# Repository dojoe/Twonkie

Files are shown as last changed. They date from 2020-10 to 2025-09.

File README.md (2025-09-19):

# Twonkie - a USB-PD sniffer based on Google's [Twinkie](https://www.chromium.org/chromium-os/developer-library/guides/hardware-schematics/twinkie/)

Twonkie is a USB-PD sniffer/injector/sink based on a Google project called Twinkie, re-engineered to be made in one-off quantities by mere mortals.

Twinkie is a great and pretty low-cost solution, and it's open-source so anyone could make their own, but unfortunately the Twinkie design uses a six-layer PCB and all BGA/wafer-scale parts - both of which are usually unavailable to the humble hobbyist.

So I designed the Twonkie, a slightly wonky sibling of Twinkie. It uses a four-layer PCB that can be manufactured cheaply by lots of services like OSHPark, and it makes a point to use only leaded parts for easier soldering (though the main microcontroller can optionally be QFN too via a dual footprint). The most difficult parts are likely the passives which are all 0402, and the USB-C connectors which are used in an unconventional way by misusing 90° upright connectors as 1.6mm straddle mounts (living up to the concept of being wonky).

## What does it look like?

Lookie here!

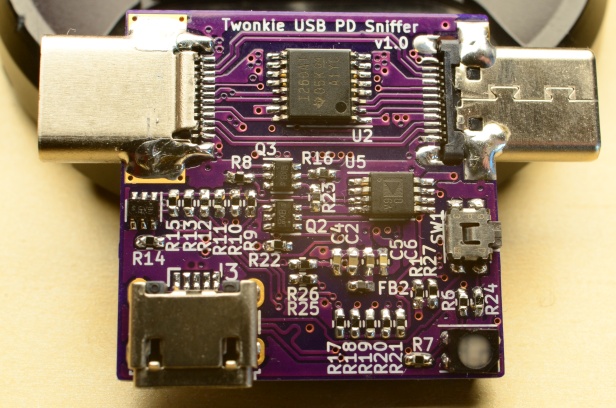
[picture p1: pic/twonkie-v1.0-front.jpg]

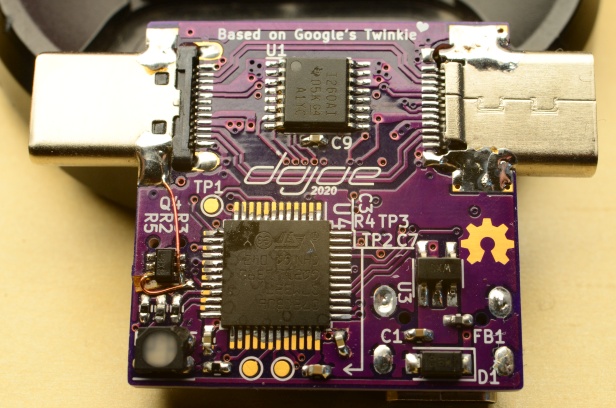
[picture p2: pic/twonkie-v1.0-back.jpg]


The PCB is exactly 1 inch squared, so $10 will get you three at OSHPark. In fact, let me take care of that for you:



_(Disclaimer: I am not affiliated with OSHPark, I just love their service to bits and they've been super helpful chaps time and time again.)_

The v1.0 and v2.0 Gerbers in this repo no longer need the botch wires around Q4 either, I'll update the photo as soon as I get the next board revision back.

## What's changed compared to the original Twinkie?

 * A bootloader button in addition to the USB_ID pin based bootloader selection.
 * Uses the INA237 part which supports the higher supply voltages of USB-PD Extended Power Range (EPR)
 * The microcontroller pins are rearranged for easier routing, so you'll need a different firmware. Binaries are provided and the firmware is easy to build from source.
 * The USB-C connectors are attached in a hair-raising straddle mount configuration. The way they're soldered to the PCB makes them rock solid though, maybe even more solid than the original Twinkie, and they transfer TB3 20Gbit/s lanes just fine.

## I see there's a v2.0 now - what's different?

The 2.0 version uses a different voltage/current monitor chip compared to Twonkie v1.0, the [INA237](ref/ina237.pdf), which supports higher bus voltages and therefore makes the Twonkie hardware ready for Extended Power Range (EPR). The INA260 used by Twonkie v1.0 (and the INA231 used by Twinkie) will take damage if subjected to the up to 48V specified by EPR.

## Sweet! How do I build my own?

I'm glad you asked! Get the board made via the OSH Park link above, or supply the v2.0 Gerbers in this repository to a PCB fab of your choice, get the parts from Digikey or Mouser or what have you, and follow the [Assembly instructions](hw/README.md) to build the device. I recommend ordering a few extra parts: Get one more of each Type-C connector since you're going to modify them in ways that might end up with a broken connector, and generously round up the number of 0402 passives since you're going to drop some of them and you will _never_ find them again :)

For the firmware, there are [Instructions for building and flashing](fw/README.md) in the [fw](fw) directory.

## None of the parts are available 😭 What do I do?

Here are some ideas about replacements for some parts that are most likely to be unavailable. None of these have been tested so you're on your own!

 * **INA237:** The INA237 is part of a device family and has two siblings with higher specs that TI claims are drop-in replacements: INA228 and INA238.
 * **STM32F072CB:** For one, the Twonkie has a dual footprint that will fit both the TQFP and QFN variants, i.e. the STM32F072CBT and STM32F072CBU. And if you are willing to sacrifice the PD sink functionaliy and only need the sniffer functionality you could also try the variants with 64k flash instead of 128k (STM32F072C8*) and only flash the first half of the firmware binary. Other device families than the F072 would require extensive firmware changes so I can't recommend that.
 * **USB-C plug / receptacle:** These might be a little trickier. Basically you need one that's meant for being mounted standing up on a board, has all USB-C pins wired out to L shaped pins and doesn't have any metal mounting prongs protruding into the board plane (or if it has you'll have to cut them off).

## I am a noob trying to solder and replicate the Twonkie. Got any beginner tips?

The KiCad schematic file contains the vendor part numbers and DigiKey order numbers for each part designator, and I exported the full list into a .csv file too - those are commonly called "Bill of materials" or BOM for short, and [this is the one for Twonkie 2.0](hw/v2.0/twonkie.bom.csv). You should be able to punch those part numbers into a parts supplier of your choice (I usually use [DigiKey](https://digikey.com/) but there are plenty others) to find the parts you need. If they have parts in stock they'll happily sell you small quantities, though at an increased price. Take care to order more of most parts than you need - especially the tiny passives (resistors, capacitors...) are easy to lose during assembly.

As for reading the schematic, it probably helps to have some familiarity with [USB-PD](https://www.usb.org/document-library/usb-power-delivery) and the [original project description](https://www.chromium.org/chromium-os/developer-library/guides/hardware-schematics/twinkie/), and then read up on the [device datasheets](ref/) to understand which part does what.

Having said all that, please be warned that the Twonkie is not exactly a noob project - unless you're already familiar with hand-soldering fine pitch SMT parts you may be in for a frustrating experience. Don't let that keep you from trying, but you should know what you're signing up for :)

# TODOs

 * [ ] Get Twinkie support upstreamed in sigrok/PulseView
 * [ ] v2.0 photos

# Similar projects

 * As luck would have it, [Greg Davill](https://github.com/gregdavill) started a project with the exact same goal at a very similar time, so there's now two of us :) https://github.com/gregdavill/PD-sniffer
 * [XenGi](https://github.com/XenGi) built a version of Twonkie v2.0 which uses a 0.8mm PCB and industry-standard straddle mount USB-C connectors. After [a bit of deliberation](https://github.com/dojoe/Twonkie/issues/10) I decided to stick with the 1.6mm PCB for stability and availability reasons but if you prefer a less haxxy way of attaching the connectors (and a 3D printed case!) feel free to check out his repo: https://gitlab.com/XenGi/Twonkie
   
# Licenses

## Hardware (as found in the `hw` subdirectory)

<p xmlns:cc="http://creativecommons.org/ns#" xmlns:dct="http://purl.org/dc/terms/">The hardware design of <a property="dct:title" rel="cc:attributionURL" href="https://github.com/dojoe/Twonkie">Twonkie</a> by <a rel="cc:attributionURL dct:creator" property="cc:attributionName" href="https://github.com/dojoe">Joachim "dojoe" Fenkes</a> is licensed under <a href="http://creativecommons.org/licenses/by/4.0/" target="_blank" rel="license noopener noreferrer" style="display:inline-block;">CC BY 4.0</a></p>

## Firmware (as found in the `fw` subdirectory)

The source code for the Twonkie's firmware is licensed under the 3-clause BSD license, see [its LICENSE file](fw/LICENSE).

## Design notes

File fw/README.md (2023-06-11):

# Twinkie / Twonkie firmware sources

These sources are the original sources from the Chromium OS Embedded Controller
project, stripped down to the minimum required to build the Twinkie/Twonkie
firmware.

# Building

## Prerequisites

Beyond what your distro should provide anyway, you'll need `arm-none-eabi-gcc`
to build the firmware and not much else.

## Building the Twonkie firmware

 * `make -j BOARD=twonkie`  for Twonkie v1 hardware
 * `make -j BOARD=twonkiev2`  for Twonkie v2 hardware
 * `make -j BOARD=twinkie`  for the original Twinkie

The completed firmware will end up in `build/<BOARD>/ec.bin` and can be flashed
as is.

Or you can run `buildall.sh` to build all three images.

## Pre-built firmware

Check out the GitHub [Releases](https://github.com/dojoe/Twonkie/releases) page
for pre-built firmware images.

# Flashing

For flashing you'll need `dfu-util`. On Linux your package manager should offer
a package for it, for Windows you can find builds on their [SourceForge site](http://dfu-util.sourceforge.net/).

## Enter the bootloader

There are several ways to put Twinkie or Twonkie into bootloader mode:

 1. Twonkie only: Via the bootloader button. Press and hold the button while
    plugging in the USB cable.
 2. Via a cursed OTG cable. Plug an A-to-A USB cable into an USB-OTG adapter and
    use that concoction to connect Twonkie to your computer.
    The OTG adapter pulls the ID pin on the Micro-B connector high, a circuit on
    the Twonkie board detects this and asserts the STM32's bootloader signal.
 3. Via the `dfu` command at the USB console. Obviously this only works once
    there's a working firmware on the chip.

## Flash the firmware

`dfu-util -a 0 -s 0x08000000 -D ec.bin`

## Exit the bootloader

If you entered DFU mode via the button or a cursed cable, just unplug Twonkie
and plug it in again using a regular cable.

If you entered DFU mode via the `dfu` command at the console, you have to
switch back using this command:

`dfu-util -a 0 -s 0x08000000:force:unprotect`

This will not actually flash anything, it will only exit the bootloader.

# USB console

## Linux

Twonkie has a simple console mode using a pair of bulk USB endpoints. In Linux,
the USB serial driver should support this mode and make the console available as
`/dev/ttyUSBx`. If that device doesn't show up immediately you can try

    sudo modprobe usbserial
    echo '18d1 500A' | sudo tee /sys/bus/usb-serial/drivers/generic/new_id

## Windows

For Windows there's a simple USB console program in [util/shell.py](util/shell.py).
It requires the `libusb1` package from PyPI.

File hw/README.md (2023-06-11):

# Before you begin

## Recommended tools (apart from the usual)

The board is too tiny to stay put from its own weight so you'll need a proper vise. "Third Hand"s are no good for this since they can't clamp small boards properly and aren't stable enough. I recommend a StickVise or similar.

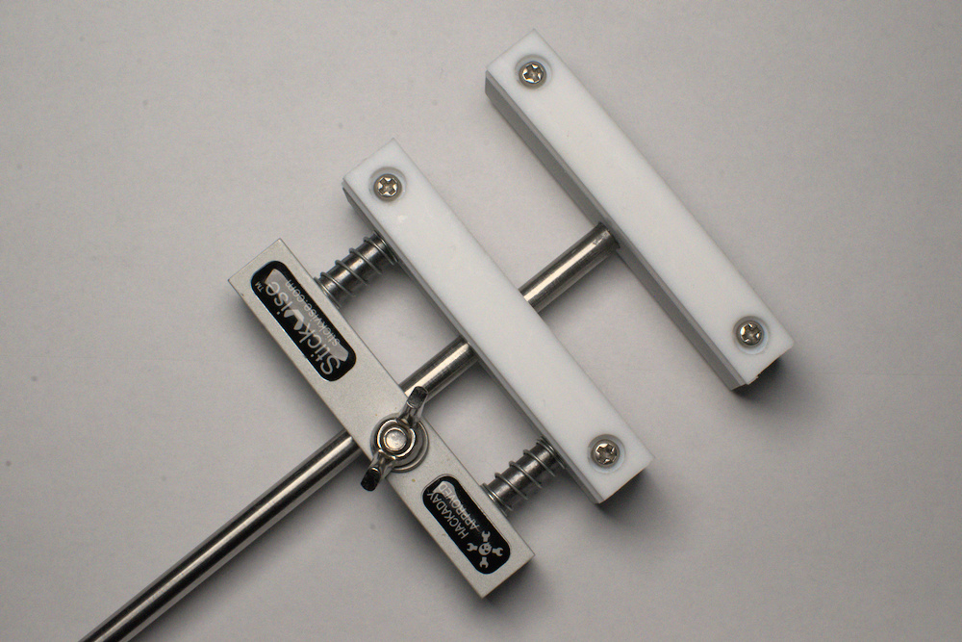
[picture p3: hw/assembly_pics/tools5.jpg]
[](assembly_pics/tools5.jpg)

A knife with a straight, strong blade.

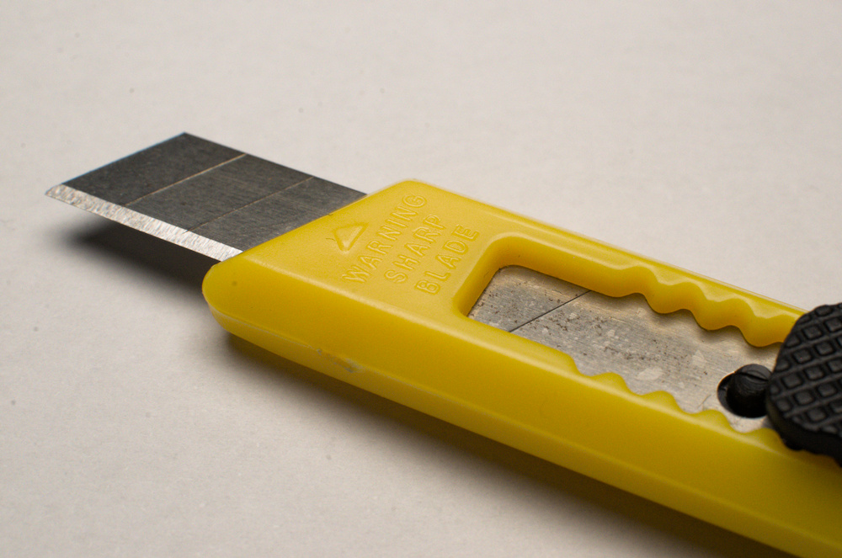
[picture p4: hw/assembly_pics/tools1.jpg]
[](assembly_pics/tools1.jpg)

Non-serrated pliers.

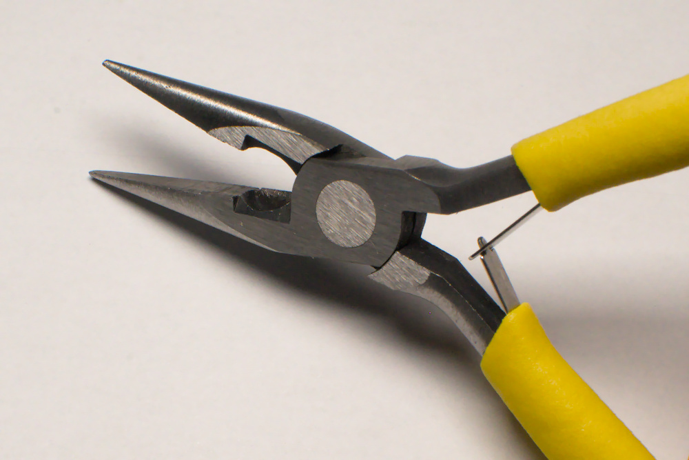
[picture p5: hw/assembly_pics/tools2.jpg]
[](assembly_pics/tools2.jpg)

You can solder everything using a smallish chisel tip and you'll be fine.
For enhanced comfort, a fine angled tip makes the passives much easier. I used a TS80-J02 with great success.

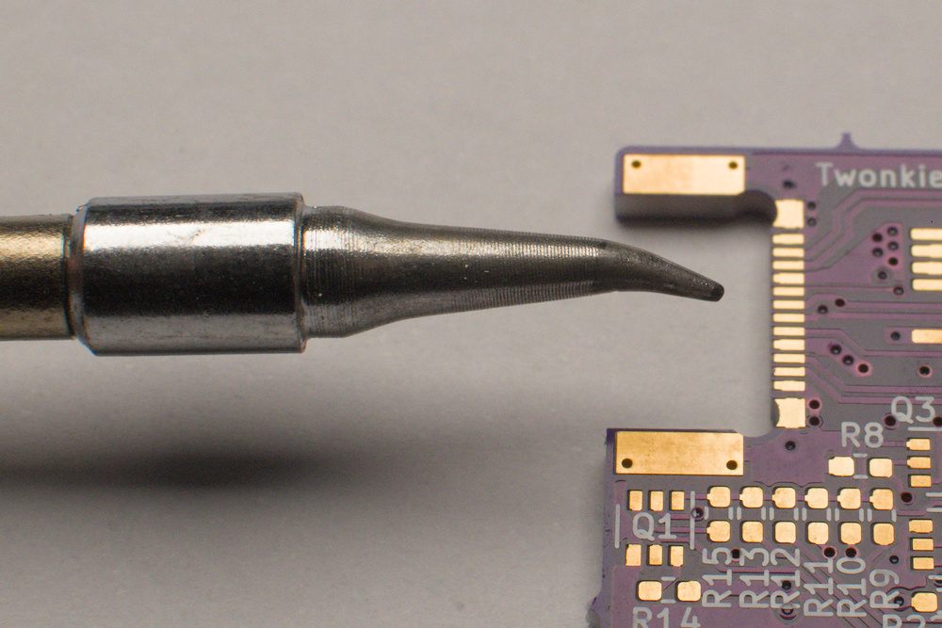
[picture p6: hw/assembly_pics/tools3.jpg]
[](assembly_pics/tools3.jpg)

Gel flux. Liquid flux evaporates too quickly for my taste. I use Edsyn FL-22 for everything but there's plenty other good stuff out there too.

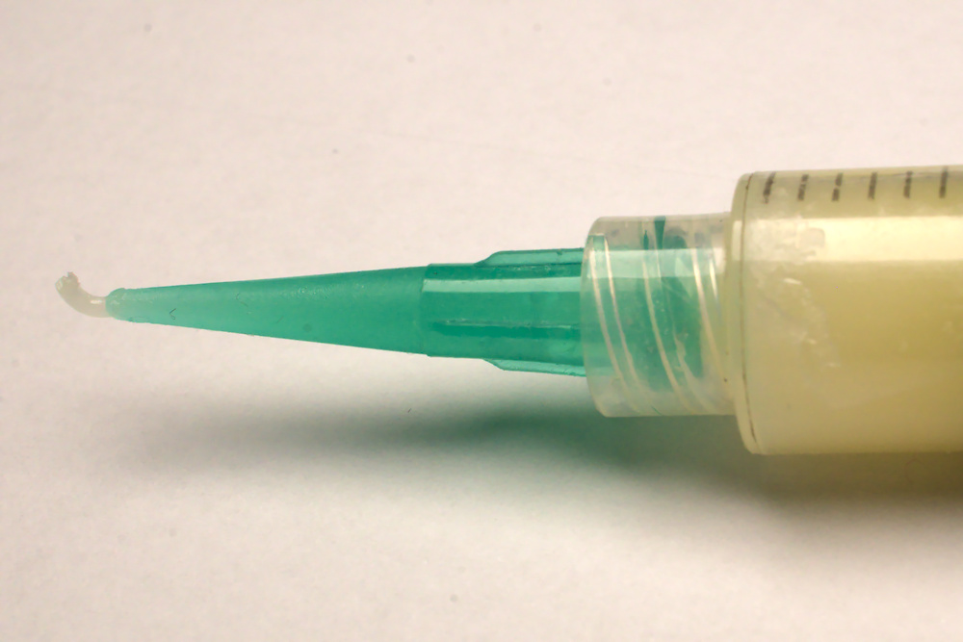
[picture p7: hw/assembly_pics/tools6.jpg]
[](assembly_pics/tools6.jpg)

A watchmaker's loupe, more for inspection than for the actual soldering. Of all the tools I acquired last year, this super cheap 7x loupe made the biggest difference and it's never leaving my workbench again. Have a strong light (such as a phone camera LED) at the ready for inspection too, there's no such thing as "too much light".

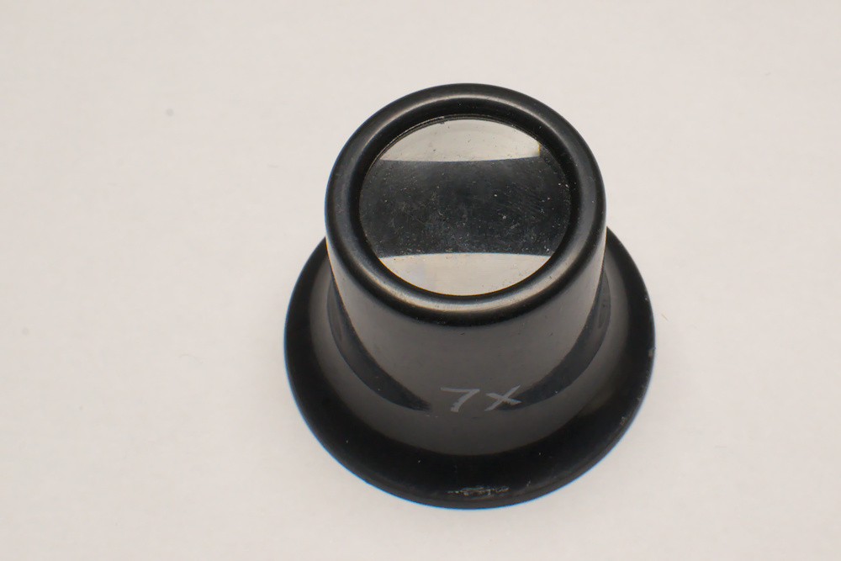
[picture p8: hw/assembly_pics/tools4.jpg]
[](assembly_pics/tools4.jpg)

## General tips

 * Keep both the schematics and the board file open while you build, you'll likely want to refer back to them more often than not.

 * I wholeheartedly recommend this thread by [@thingskatedid](https://twitter.com/thingskatedid): https://twitter.com/thingskatedid/status/1348234262886039558

 * **The passives are indistinguishable once taken out of their tapes!**
   * Always work with a single value at a time
   * Only remove as many components from the tape as you need right now
   * Immediately put the tape back into the pouch it came in, as that's where the value is noted - or write the value onto the tape.

 * For each group of passives below, it saves time to batch up different types of operations: First put a small solder blob on one pad of each site, then tack down each component, then solder the other side for all components in a row.

 * If the solder joints on nearby passives blob together a lot, use some flux and a little less solder. It's also a good idea to make a final flux pass across the finished passives just like you would be drag soldering a leaded part, it makes the solder joints look a lot nicer.

# Assembly instructions

These instructions are optimized for hand assembly; the components are grouped in a way that if you follow the groups in order you should never have one component in the way of soldering another. Within a given group the order does not matter; I recommend doing all components of one value before moving on to the next value.

The overall order of assembly is:
 1. Back side components
 2. Front side components
 3. Basic connectivity/bootloader test
 4. USB-C connectors

## Part 1: Back side

We start on the back side because that's where the STM32 sits which is the most daunting to solder, and because the components on that side are generally flatter so if you _have_ to solder without a vise they won't make the board as wobbly when you do the front side.

If your STM32 is a QFN part, take extra care to inspect its solder joints after you put it down. Once the board is fully populated any bad solder joints here will be hard to fix.

| Group | Components | Value |
|---|---|---|
| 1 | U4 | STM32 |
| 2 | R3 | 400 |
| | R2, R5 | 620 |
| 3 | DS1 | LED |
| 4 | C3, C8 | 100n |
| | C7 | 4.7µ |
| | C1 | 1µ |
| | R4 | 400 |
| | FB1 | Ferrite Bead |
| 5 | D1, U1, U3, Q4, R28 | |

## Part 2: Front side

| Group | Components | Value |
|---|---|---|
| 6 | Q1, Q2, Q3 | NFET |
| 8 | R9, R17, R25, R26 | 4k75 |
| | R10, R18 | 1k |
| | R11, R19 | 12k1 |
| | R12, R20 | 5k11 |
| | R6, R7 | 400 |
| | R15, R23, R24 | 100 |
| | R14, R22 | 200 |
| 9 | R1, R8, R13, R16, R21, R27 | 35k7 |
| 10 | C2 | 4u7 |
| | C4, C9 | 100n |
| | C5 | 1u |
| | C6 | 10n |
| 11 | FB2 | Ferrite Bead  |
| 12 | DS2, U5, U2, J3, SW1, R29  | |

## Part 3: Basic connectivity / bootloader test

This step is done on the not-quite-finished Twonkie because if anything isn't right the board is much easier to hold in the vise without two USB-C connector sticking out.

1. Double check all components:
   * Are all ICs oriented the right way?
   * Did you miss any solder joints?
   * Do you see any obvious solder bridges?
2. Measure resistance between the 3V3 rail and GND, this is easiest at the output side of U3.
   Kiloohms are good, Ohms are an indication of a short somewhere.
3. Do the same on the input side of U3.
4. Hold down the bootloader switch and plug the dongle in via the Micro-B connector.
   It should now enumerate as the bootloader (VID 0x0483, PID 0xDF11, "STM32 BOOTLOADER")
5. Flash the firmware via the bootloader, then unplug and plug back in to boot the Twonkie firmware.
   * Check out the [Firmware README](../fw/README.md) for building and flashing instructions.
6. You can test the LED using the serial shell:
   * `tw sink` puts the device into sink mode where the firmware doesn't keep overwriting the LED state.
     You may need to reconnect the shell after this.
   * `gpioset LED_B_L 0` turns the blue LED on, `gpioset LED_B_L 1` turns it off.
   * Same for `LED_R_L` and `LED_G_L`
7. Check I2C connectivity to the two INA260 monitors:
   * `ina 0` attempts to access U1, `ina 1` does so for U2

That's all we can test for now, let's finish the board next.

## Part 4: USB-C connectors

The USB-C connectors are used in an unorthodox way: Straddle mount USB-C connectors for 1.6mm boards don't exist, so we take connectors meant for right-angle surface mounting and modify them into our own custom straddle mount configuration. With those modifications the solder connections work really well, and we achieve mechanical stability by soldering the connector shields to the board all around.

We start out with the unmodified connector. This is the receptacle but the steps for the plug are identical.

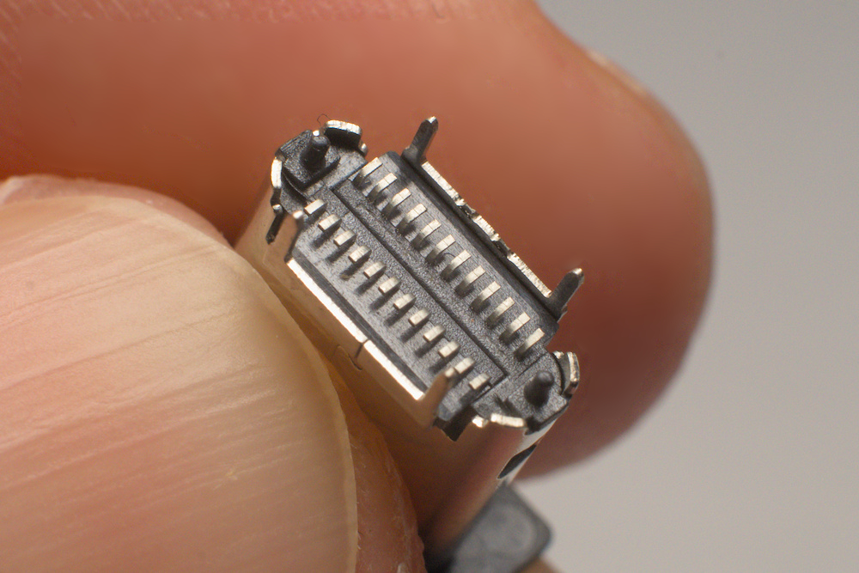
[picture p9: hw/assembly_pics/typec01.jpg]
[](assembly_pics/typec01.jpg)

First, the mounting legs have to get out of the way. Grab them with your pliers and bend them back and forth until they break off.

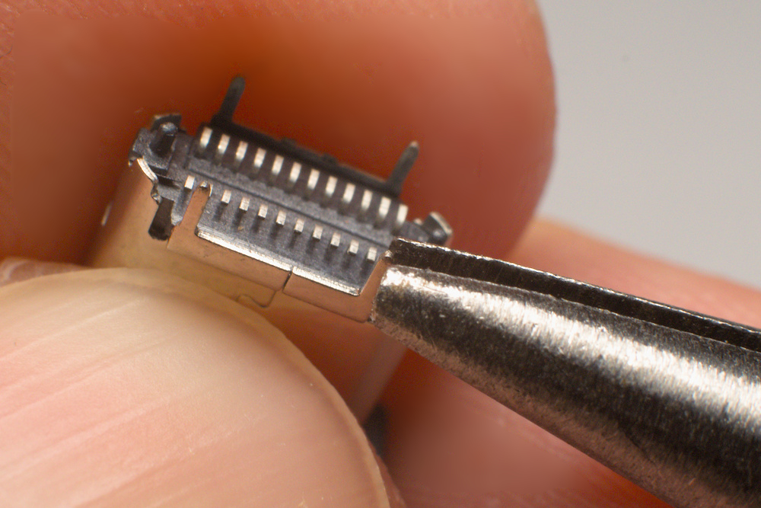
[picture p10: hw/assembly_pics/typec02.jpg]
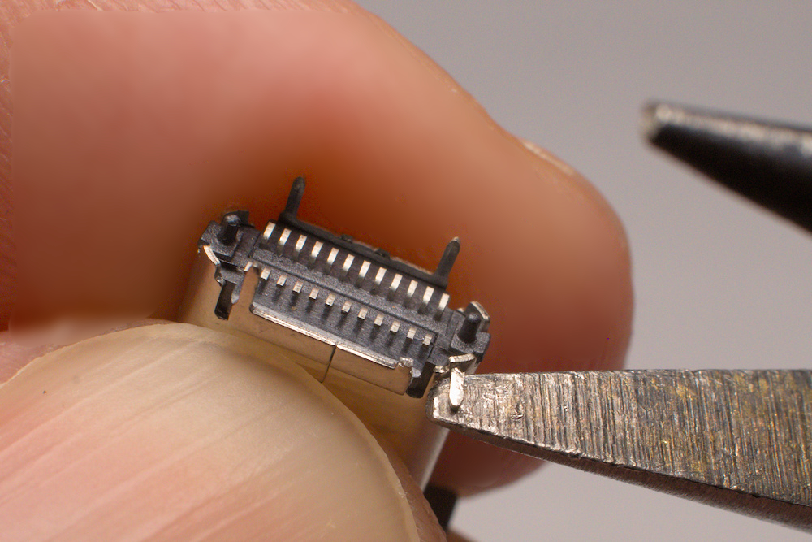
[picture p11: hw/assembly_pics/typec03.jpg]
[](assembly_pics/typec02.jpg)[](assembly_pics/typec03.jpg)

Next up, the locating pegs have to go too. Cut them off close to the base.

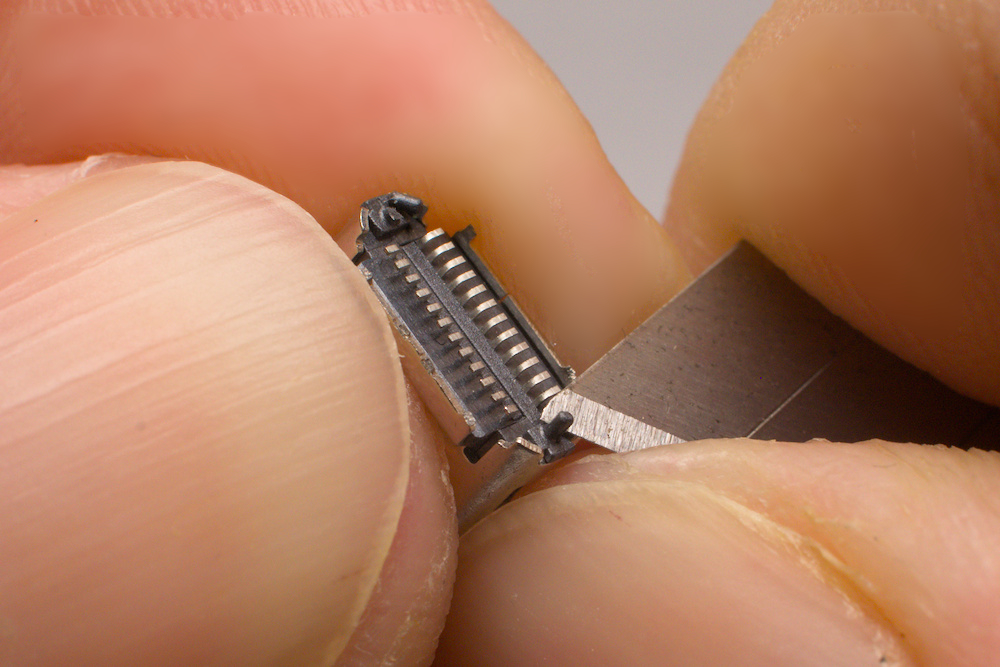
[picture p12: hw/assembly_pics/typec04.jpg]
[](assembly_pics/typec04.jpg)

Now comes the tricky part: We have to bend the pins of the connector slightly inwards so they touch the board edge at an angle, but not so much that they don't reach the board edge or break off. The photos should give you an idea of how far to bend them.

Start by sliding the knife under roughly a quarter to half the pins on one side, and gently bend them inwards. Bending only part of the pins at once requires less force and therefore allows for better control. Take care to **rotate** the knife blade around the long axis, as opposed to using it as a lever, so that all pins receive equal force and bend the same way.

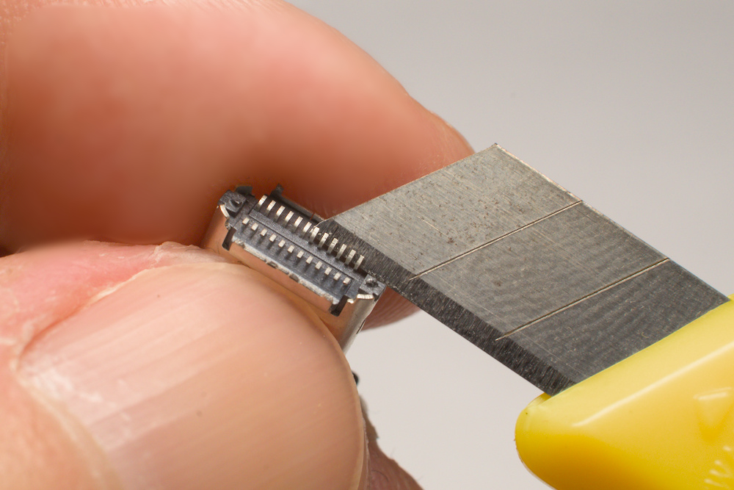
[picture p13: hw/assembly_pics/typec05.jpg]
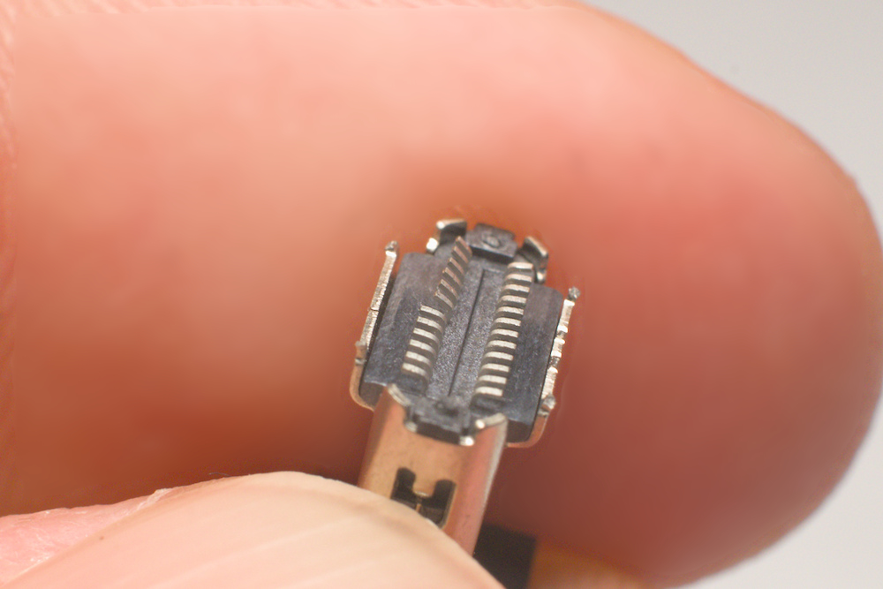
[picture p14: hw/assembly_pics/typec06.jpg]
[](assembly_pics/typec05.jpg)[](assembly_pics/typec06.jpg)

Move along the row of pins, bending groups of pins inwards until the entire row is bent.

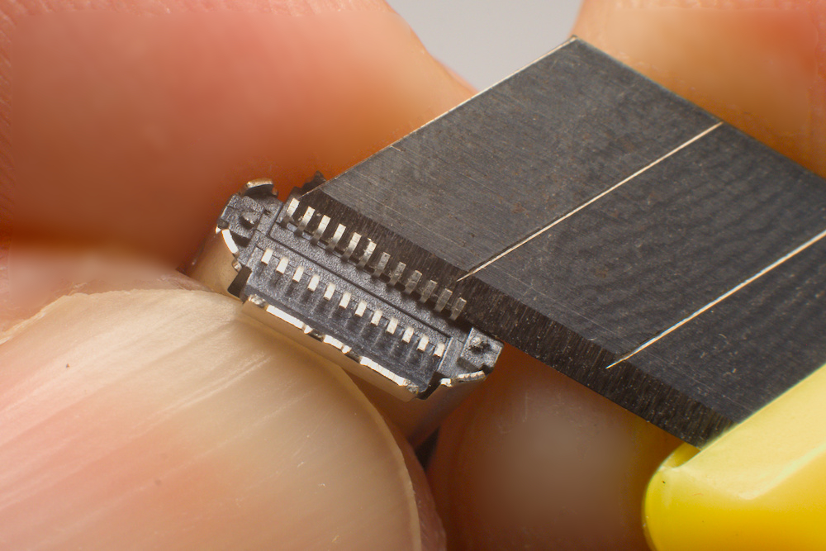
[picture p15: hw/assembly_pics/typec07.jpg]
[](assembly_pics/typec07.jpg)

Repeat the same process on the other side; the end result should look something like this:

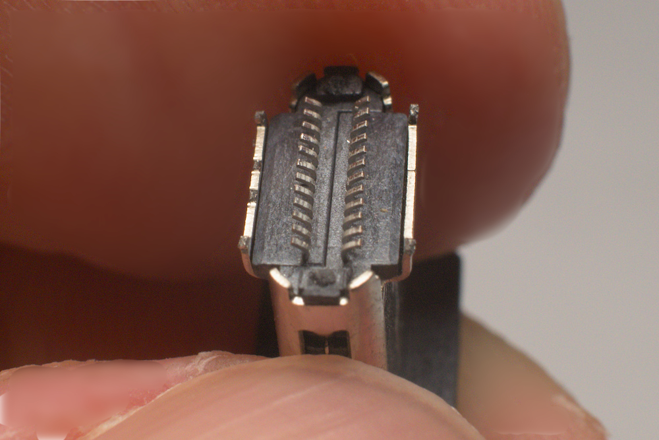
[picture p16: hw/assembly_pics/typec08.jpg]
[](assembly_pics/typec08.jpg)

Now you can slide the connector into its place on the PCB. The PCB is designed such that the shell sits inside the PCB with a slight press fit. If you feel it's jammed in there too tightly you can simply sand off a little bit of the PCB, but sand off only very little and try to sand off both sides equally to maintain pin alignment.

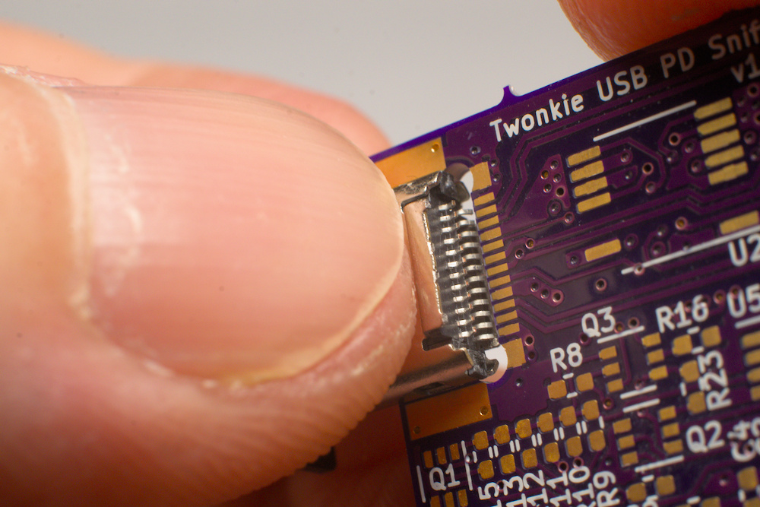
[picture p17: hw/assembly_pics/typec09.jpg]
[](assembly_pics/typec09.jpg)

Push the connector all the way towards the board edge and adjust its position until it sits exactly centered and in line with the board:

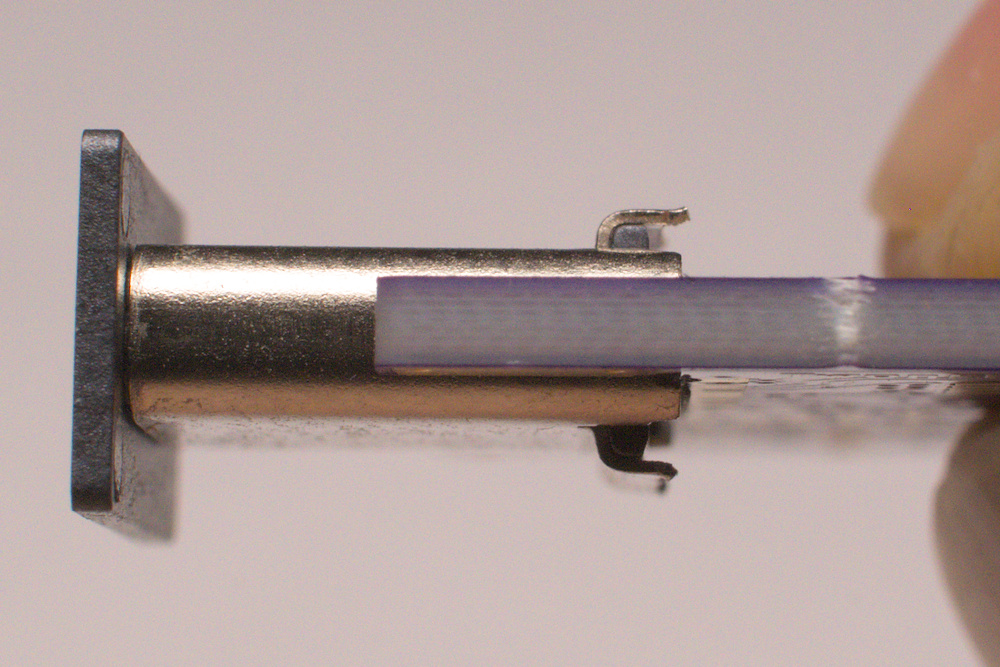
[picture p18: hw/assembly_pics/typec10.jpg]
[](assembly_pics/typec10.jpg)

The pins on both sides should now align with the pads and touch the corner of the board edge. If there's a tiny gap that's no problem, the solder will bridge that. Larger gaps need to be fixed by adjusting the connector's position or bending the pins to compensate.

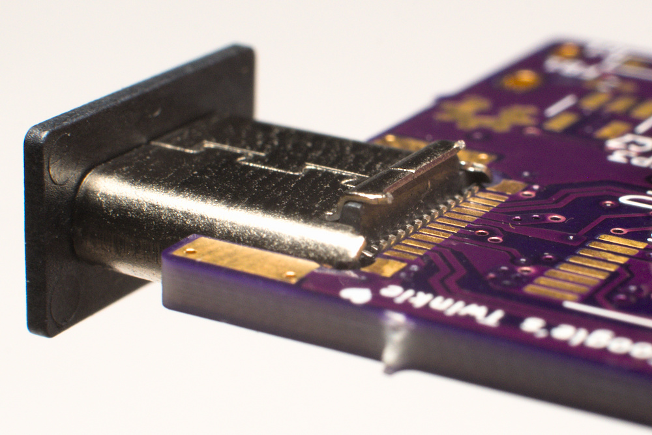
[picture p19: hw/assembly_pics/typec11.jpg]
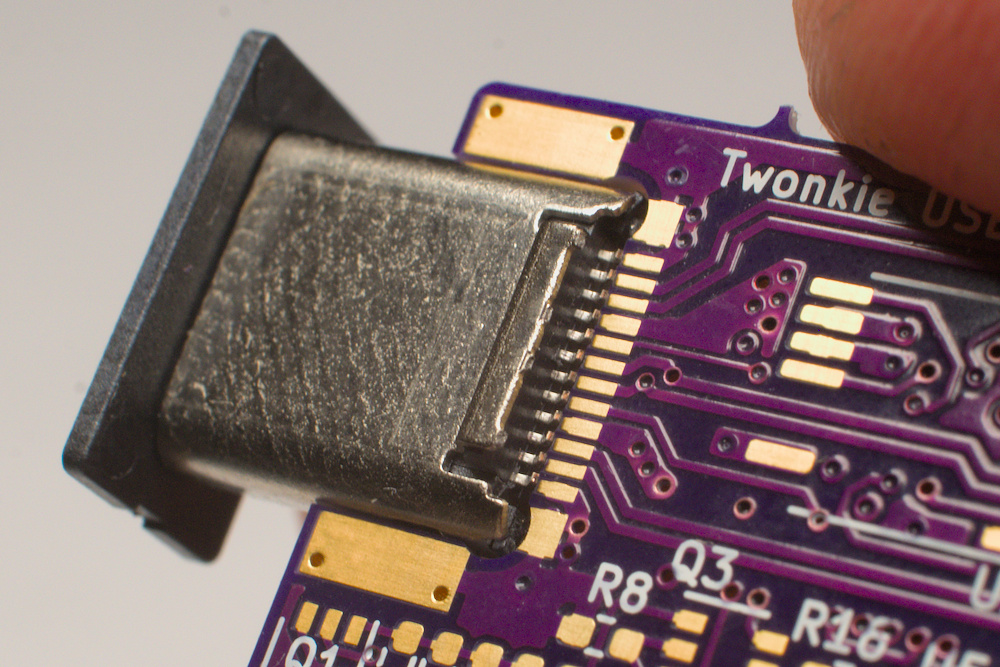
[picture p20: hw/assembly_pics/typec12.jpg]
[](assembly_pics/typec11.jpg)[](assembly_pics/typec12.jpg)

Once you're satisfied with the connector, tack down _one_ pin on one board side, double check that everything still looks good, then tack down _one_ pin on the opposite side. Triple check that everything still looks good, then you can drag solder all the pins into place.

When the pins have all been soldered, inspect them for missing connections or solder bridges and correct any that come up.

Finally you can solder down the shells: Using a soldering iron that can pump out a bit of heat (TS-80 is good, TS-100 is better, a powerful temperature controlled soldering station is best), first just pre-heat the shell for a bit, then add some solder and make sure it wets along the entire length of the neighboring pad. Then you can start heating the pad too and add loads of solder to make a solid connection. Do this on all four mounting pads and the connector won't go anywhere.

## Part 5: Enjoy!

And that's it! Clean your board with isopropanol and have fun with your new PD sniffer!

### Test 1: Sniff some power supply traffic

For starters, you can open a shell, type `tw trace on` and plug Twonkie in between a PD power supply and sink to watch them negotiate a power contract.

A very good test for many of the board devices is to do this in all four possible combinations of input and output plug orientation. The supply and sink should be able to negotiate a contract in all orientations, and Twonkie should be able to trace all of this. If some orientations don't work, check the solder joints on the USB-C connectors for bridges or opens - especially opens can be very sneaky with the haxxy edge mount we're using. If the connectors look alright, check the board devices next - especially the resistor banks and transistors are likely culprits since they directly interact with the USB-C control channels.

### Test 2: Twonkie as sink

The second test would be to attach only a power supply to Twonkie, with no sink at the other end, and type `tw sink` at the shell to put Twonkie into sink mode. (You may have to reconnect to the shell since Twonkie reboots into a different firmware.) Once in sink mode you can type `tw vbus` to watch what voltage the supply provides, and `pd 0 dev X` will limit the negotiated voltage to a maximum of `X` volts, so you can step through various supply voltages and watch them change. Test this in either plug orientation too; if you're having problems here you should double check the resistor banks on the control channels.

To go from sink mode back to sniffer mode you can type `reboot` at the shell.

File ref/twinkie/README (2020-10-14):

Twinkie USB Type-C debug board schematic, layout, and enclosure

Twinkie is a small debug board for USB Type-C that enables in-line sniffing,
packet injection, and power metrics.

All content is licensed under a Creative Commons Attribution 2.5 license.

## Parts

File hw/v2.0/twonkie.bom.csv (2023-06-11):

Source: | D:\Projects\Twonkie\hw\twonkie.kicad_sch
Date: | 2023-06-11 21:32:36
Tool: | Eeschema (6.0.10)
Generator: | C:\Program Files\KiCad\6.0\bin\scripting\plugins/bom_csv_grouped_by_value.py
Component Count: | 56
Individual Components:
Item | Qty | Reference(s) | Value | LibPart | Footprint | Datasheet | DigiKey P/N | I2C addr | Manufacturer | Mfg P/N
 |  | C1 | 1u | Device:C_Small | Capacitor_SMD:C_0402_1005Metric_Pad0.74x0.62mm_HandSolder | ~ | 1276-1235-1-ND |  | Samsung Electro-Mechanics | CL05A105MQ5NNNC
 |  | C2 | 4.7u | Device:C_Small | Capacitor_SMD:C_0402_1005Metric_Pad0.74x0.62mm_HandSolder | ~ | 1276-1481-1-ND |  | Samsung Electro-Mechanics | CL05A475KQ5NRNC
 |  | C3 | 100n | Device:C_Small | Capacitor_SMD:C_0402_1005Metric_Pad0.74x0.62mm_HandSolder | ~ | 1276-6720-1-ND |  | Samsung Electro-Mechanics | CL05B104KA5NNNC
 |  | C4 | 100n | Device:C_Small | Capacitor_SMD:C_0402_1005Metric_Pad0.74x0.62mm_HandSolder | ~ | 1276-6720-1-ND |  | Samsung Electro-Mechanics | CL05B104KA5NNNC
 |  | C5 | 1u | Device:C_Small | Capacitor_SMD:C_0402_1005Metric_Pad0.74x0.62mm_HandSolder | ~ | 1276-1235-1-ND |  | Samsung Electro-Mechanics | CL05A105MQ5NNNC
 |  | C6 | 10n | Device:C_Small | Capacitor_SMD:C_0402_1005Metric_Pad0.74x0.62mm_HandSolder | ~ | 1276-1028-1-ND |  | Samsung Electro-Mechanics | CL05B103KB5NNNC
 |  | C7 | 4.7u | Device:C_Small | Capacitor_SMD:C_0402_1005Metric_Pad0.74x0.62mm_HandSolder | ~ | 1276-1481-1-ND |  | Samsung Electro-Mechanics | CL05A475KQ5NRNC
 |  | C8 | 100n | Device:C_Small | Capacitor_SMD:C_0402_1005Metric_Pad0.74x0.62mm_HandSolder | ~ | 1276-6720-1-ND |  | Samsung Electro-Mechanics | CL05B104KA5NNNC
 |  | C9 | 100n | Device:C_Small | Capacitor_SMD:C_0402_1005Metric_Pad0.74x0.62mm_HandSolder | ~ | 1276-6720-1-ND |  | Samsung Electro-Mechanics | CL05B104KA5NNNC
 |  | D1 | BZT52C5V6 | Diode:BZT52Bxx | Diode_SMD:D_SOD-123 | https://diotec.com/tl_files/diotec/files/pdf/datasheets/bzt52b2v4.pdf | BZT52C5V6-13-FDICT-ND |  | Diodes Inc. | BZT52C5V6-13-F
 |  | DS1 | CLVBA-FKA | Device:LED_RABG | LED_SMD:LED_Cree-PLCC4_3.2x2.8mm_CCW | ~ | CLVBA-FKA-CAEDH8BBB7A363CT-ND |  | Cree | CLVBA-FKA-CAEDH8BBB7A363
 |  | DS2 | CLVBA-FKA | Device:LED_RABG | LED_SMD:LED_Cree-PLCC4_3.2x2.8mm_CCW | ~ | CLVBA-FKA-CAEDH8BBB7A363CT-ND |  | Cree | CLVBA-FKA-CAEDH8BBB7A363
 |  | FB1 | 600@100MHz | Device:FerriteBead_Small | Inductor_SMD:L_0402_1005Metric_Pad0.77x0.64mm_HandSolder | ~ | 490-1006-1-ND |  | MuRata | BLM15AG601SN1D
 |  | FB2 | 600@100MHz | Device:FerriteBead_Small | Inductor_SMD:L_0402_1005Metric_Pad0.77x0.64mm_HandSolder | ~ | 490-1006-1-ND |  | MuRata | BLM15AG601SN1D
 |  | J1 | USB4151 | twonkie:USB_C_Plug | twonkie:GCT_USB4151_EdgeMount | https://www.usb.org/sites/default/files/documents/usb_type-c.zip | 2073-USB4151-GF-CCT-ND |  | GCT | USB4151-GF-C
 |  | J2 | 690-024-294T331 | twonkie:USB_C_Receptacle | twonkie:EDAC_690-024-294T331_EdgeMount | https://www.usb.org/sites/default/files/documents/usb_type-c.zip | 2073-USB4070-30-CCT-ND |  | GCT | USB4070-30-C
 |  | J3 | 629105150521 | Connector:USB_B_Micro | twonkie:USB_Micro-B_Wuerth_629105150521_HandSolder | ~ | 732-5960-1-ND |  | Würth | 629105150521
 |  | Q1 | BSD840N | Transistor_FET:FDG6335N | Package_TO_SOT_SMD:SOT-363_SC-70-6 | http://www.gneic.com/product/datasheet/FDG6335N-1122853.pdf | BSD840NH6327XTSA1CT-ND |  | Infineon | BSD840NH6327XTSA1
 |  | Q2 | BSD840N | Transistor_FET:FDG6335N | Package_TO_SOT_SMD:SOT-363_SC-70-6 | http://www.gneic.com/product/datasheet/FDG6335N-1122853.pdf | BSD840NH6327XTSA1CT-ND |  | Infineon | BSD840NH6327XTSA1
 |  | Q3 | BSD840N | Transistor_FET:FDG6335N | Package_TO_SOT_SMD:SOT-363_SC-70-6 | http://www.gneic.com/product/datasheet/FDG6335N-1122853.pdf | BSD840NH6327XTSA1CT-ND |  | Infineon | BSD840NH6327XTSA1
 |  | Q4 | BSD840N | Transistor_FET:FDG6335N | Package_TO_SOT_SMD:SOT-363_SC-70-6 | http://www.gneic.com/product/datasheet/FDG6335N-1122853.pdf | BSD840NH6327XTSA1CT-ND |  | Infineon | BSD840NH6327XTSA1
 |  | R1 | 35k7 | Device:R | Resistor_SMD:R_0402_1005Metric_Pad0.72x0.64mm_HandSolder | ~ |  |  | Yageo | RC0402FR-0735K7L
 |  | R2 | 620 | Device:R | Resistor_SMD:R_0402_1005Metric_Pad0.72x0.64mm_HandSolder | ~ |  |  | Yageo | RC0402FR-07620RL
 |  | R3 | 400 | Device:R | Resistor_SMD:R_0402_1005Metric_Pad0.72x0.64mm_HandSolder | ~ |  |  | Yageo | RC0402FR-07402RL
 |  | R4 | 400 | Device:R | Resistor_SMD:R_0402_1005Metric_Pad0.72x0.64mm_HandSolder | ~ |  |  | Yageo | RC0402FR-07402RL
 |  | R5 | 620 | Device:R | Resistor_SMD:R_0402_1005Metric_Pad0.72x0.64mm_HandSolder | ~ |  |  | Yageo | RC0402FR-07620RL
 |  | R6 | 400 | Device:R | Resistor_SMD:R_0402_1005Metric_Pad0.72x0.64mm_HandSolder | ~ |  |  | Yageo | RC0402FR-07402RL
 |  | R7 | 400 | Device:R | Resistor_SMD:R_0402_1005Metric_Pad0.72x0.64mm_HandSolder | ~ |  |  | Yageo | RC0402FR-07402RL
 |  | R8 | 35k7 | Device:R | Resistor_SMD:R_0402_1005Metric_Pad0.72x0.64mm_HandSolder | ~ |  |  | Yageo | RC0402FR-0735K7L
 |  | R9 | 4k75 | Device:R | Resistor_SMD:R_0402_1005Metric_Pad0.72x0.64mm_HandSolder | ~ |  |  | Yageo | RC0402FR-074K75L
 |  | R10 | 1k | Device:R | Resistor_SMD:R_0402_1005Metric_Pad0.72x0.64mm_HandSolder | ~ |  |  | Yageo | RC0402FR-071KL
 |  | R11 | 12k1 | Device:R | Resistor_SMD:R_0402_1005Metric_Pad0.72x0.64mm_HandSolder | ~ |  |  | Yageo | RC0402FR-0712K1L
 |  | R12 | 5k11 | Device:R | Resistor_SMD:R_0402_1005Metric_Pad0.72x0.64mm_HandSolder | ~ |  |  | Yageo | RC0402FR-075K11L
 |  | R13 | 35k7 | Device:R | Resistor_SMD:R_0402_1005Metric_Pad0.72x0.64mm_HandSolder | ~ |  |  | Yageo | RC0402FR-0735K7L
 |  | R14 | 200 | Device:R | Resistor_SMD:R_0402_1005Metric_Pad0.72x0.64mm_HandSolder | ~ |  |  | Yageo | RC0402FR-07200RL
 |  | R15 | 100 | Device:R | Resistor_SMD:R_0402_1005Metric_Pad0.72x0.64mm_HandSolder | ~ |  |  | Yageo | RC0402FR-07100RL
 |  | R16 | 35k7 | Device:R | Resistor_SMD:R_0402_1005Metric_Pad0.72x0.64mm_HandSolder | ~ |  |  | Yageo | RC0402FR-0735K7L
 |  | R17 | 4k75 | Device:R | Resistor_SMD:R_0402_1005Metric_Pad0.72x0.64mm_HandSolder | ~ |  |  | Yageo | RC0402FR-074K75L
 |  | R18 | 1k | Device:R | Resistor_SMD:R_0402_1005Metric_Pad0.72x0.64mm_HandSolder | ~ |  |  | Yageo | RC0402FR-071KL
 |  | R19 | 12k1 | Device:R | Resistor_SMD:R_0402_1005Metric_Pad0.72x0.64mm_HandSolder | ~ |  |  | Yageo | RC0402FR-0712K1L
 |  | R20 | 5k11 | Device:R | Resistor_SMD:R_0402_1005Metric_Pad0.72x0.64mm_HandSolder | ~ |  |  | Yageo | RC0402FR-075K11L
 |  | R21 | 35k7 | Device:R | Resistor_SMD:R_0402_1005Metric_Pad0.72x0.64mm_HandSolder | ~ |  |  | Yageo | RC0402FR-0735K7L
 |  | R22 | 200 | Device:R | Resistor_SMD:R_0402_1005Metric_Pad0.72x0.64mm_HandSolder | ~ |  |  | Yageo | RC0402FR-07200RL
 |  | R23 | 100 | Device:R | Resistor_SMD:R_0402_1005Metric_Pad0.72x0.64mm_HandSolder | ~ |  |  | Yageo | RC0402FR-07100RL
 |  | R24 | 100 | Device:R | Resistor_SMD:R_0402_1005Metric_Pad0.72x0.64mm_HandSolder | ~ |  |  | Yageo | RC0402FR-07100RL
 |  | R25 | 4k75 | Device:R | Resistor_SMD:R_0402_1005Metric_Pad0.72x0.64mm_HandSolder | ~ |  |  | Yageo | RC0402FR-074K75L
 |  | R26 | 4k75 | Device:R | Resistor_SMD:R_0402_1005Metric_Pad0.72x0.64mm_HandSolder | ~ |  |  | Yageo | RC0402FR-074K75L
 |  | R27 | 35k7 | Device:R | Resistor_SMD:R_0402_1005Metric_Pad0.72x0.64mm_HandSolder | ~ |  |  | Yageo | RC0402FR-0735K7L
 |  | R28 | 0.012 | Device:R_Shunt | twonkie:R_Shunt_Ohmite_LVK12 | https://www.ohmite.com/assets/docs/res_lvk.pdf | LVK12R012FERCT-ND
 |  | R29 | 0.012 | Device:R_Shunt | twonkie:R_Shunt_Ohmite_LVK12 | https://www.ohmite.com/assets/docs/res_lvk.pdf | LVK12R012FERCT-ND
 |  | SW1 | EVQ-P7M01P | Switch:SW_Push | Button_Switch_SMD:SW_SPST_EVQP7C | http://www.apem.com/int/index.php?controller=attachment&id_attachment=1371 | P16770CT-ND |  | Panasonic | EVQ-P7M01P
 |  | U1 | INA237 | twonkie:INA237 | Package_SO:VSSOP-10_3x3mm_P0.5mm | https://www.ti.com/lit/ds/symlink/ina237.pdf | 296-INA237AIDGSRCT-ND | 0x40 | TI | INA237AIDGSR
 |  | U2 | INA237 | twonkie:INA237 | Package_SO:VSSOP-10_3x3mm_P0.5mm | https://www.ti.com/lit/ds/symlink/ina237.pdf | 296-INA237AIDGSRCT-ND | 0x43 | TI | INA237AIDGSR
 |  | U3 | MIC5504 | Regulator_Linear:MIC5504-3.3YM5 | Package_TO_SOT_SMD:SOT-23-5_HandSoldering | https://www.analog.com/media/en/technical-documentation/data-sheets/AD8610_8620.pdf | 576-4764-1-ND |  | Microchip | MIC5504-3.3YM5-TR
 |  | U4 | STM32F072CB | MCU_ST_STM32F0:STM32F072CBTx | twonkie:LQFP-48_7x7mm_P0.5mm-QFN48-Frankenstein | http://www.st.com/st-web-ui/static/active/en/resource/technical/document/datasheet/DM00090510.pdf | 497-18747-1-ND |  | STMicro | STM32F072CBT
 |  | U5 | AD8606 | Amplifier_Operational:AD8620 | Package_SO:MSOP-8_3x3mm_P0.65mm | https://www.analog.com/media/en/technical-documentation/data-sheets/AD8610_8620.pdf | 505-AD8606ARMZ-R7CT-ND |  | Analog Devices | AD8606ARMZ-R7
Collated Components:
Item | Qty | Reference(s) | Value | LibPart | Footprint | Datasheet | DigiKey P/N | I2C addr | Manufacturer | Mfg P/N
1 | 2 | C1, C5 | 1u | Device:C_Small | Capacitor_SMD:C_0402_1005Metric_Pad0.74x0.62mm_HandSolder | ~ | 1276-1235-1-ND |  | Samsung Electro-Mechanics | CL05A105MQ5NNNC
2 | 2 | C2, C7 | 4.7u | Device:C_Small | Capacitor_SMD:C_0402_1005Metric_Pad0.74x0.62mm_HandSolder | ~ | 1276-1481-1-ND |  | Samsung Electro-Mechanics | CL05A475KQ5NRNC
3 | 4 | C3, C4, C8, C9 | 100n | Device:C_Small | Capacitor_SMD:C_0402_1005Metric_Pad0.74x0.62mm_HandSolder | ~ | 1276-6720-1-ND |  | Samsung Electro-Mechanics | CL05B104KA5NNNC
4 | 1 | C6 | 10n | Device:C_Small | Capacitor_SMD:C_0402_1005Metric_Pad0.74x0.62mm_HandSolder | ~ | 1276-1028-1-ND |  | Samsung Electro-Mechanics | CL05B103KB5NNNC
5 | 1 | D1 | BZT52C5V6 | Diode:BZT52Bxx | Diode_SMD:D_SOD-123 | https://diotec.com/tl_files/diotec/files/pdf/datasheets/bzt52b2v4.pdf | BZT52C5V6-13-FDICT-ND |  | Diodes Inc. | BZT52C5V6-13-F
6 | 2 | DS1, DS2 | CLVBA-FKA | Device:LED_RABG | LED_SMD:LED_Cree-PLCC4_3.2x2.8mm_CCW | ~ | CLVBA-FKA-CAEDH8BBB7A363CT-ND |  | Cree | CLVBA-FKA-CAEDH8BBB7A363
7 | 2 | FB1, FB2 | 600@100MHz | Device:FerriteBead_Small | Inductor_SMD:L_0402_1005Metric_Pad0.77x0.64mm_HandSolder | ~ | 490-1006-1-ND |  | MuRata | BLM15AG601SN1D
8 | 1 | J1 | USB4151 | twonkie:USB_C_Plug | twonkie:GCT_USB4151_EdgeMount | https://www.usb.org/sites/default/files/documents/usb_type-c.zip | 2073-USB4151-GF-CCT-ND |  | GCT | USB4151-GF-C
9 | 1 | J2 | 690-024-294T331 | twonkie:USB_C_Receptacle | twonkie:EDAC_690-024-294T331_EdgeMount | https://www.usb.org/sites/default/files/documents/usb_type-c.zip | 2073-USB4070-30-CCT-ND |  | GCT | USB4070-30-C
10 | 1 | J3 | 629105150521 | Connector:USB_B_Micro | twonkie:USB_Micro-B_Wuerth_629105150521_HandSolder | ~ | 732-5960-1-ND |  | Würth | 629105150521
11 | 4 | Q1, Q2, Q3, Q4 | BSD840N | Transistor_FET:FDG6335N | Package_TO_SOT_SMD:SOT-363_SC-70-6 | http://www.gneic.com/product/datasheet/FDG6335N-1122853.pdf | BSD840NH6327XTSA1CT-ND |  | Infineon | BSD840NH6327XTSA1
12 | 6 | R1, R8, R13, R16, R21, R27 | 35k7 | Device:R | Resistor_SMD:R_0402_1005Metric_Pad0.72x0.64mm_HandSolder | ~ |  |  | Yageo | RC0402FR-0735K7L
13 | 2 | R2, R5 | 620 | Device:R | Resistor_SMD:R_0402_1005Metric_Pad0.72x0.64mm_HandSolder | ~ |  |  | Yageo | RC0402FR-07620RL
14 | 4 | R3, R4, R6, R7 | 400 | Device:R | Resistor_SMD:R_0402_1005Metric_Pad0.72x0.64mm_HandSolder | ~ |  |  | Yageo | RC0402FR-07402RL
15 | 4 | R9, R17, R25, R26 | 4k75 | Device:R | Resistor_SMD:R_0402_1005Metric_Pad0.72x0.64mm_HandSolder | ~ |  |  | Yageo | RC0402FR-074K75L
16 | 2 | R10, R18 | 1k | Device:R | Resistor_SMD:R_0402_1005Metric_Pad0.72x0.64mm_HandSolder | ~ |  |  | Yageo | RC0402FR-071KL
17 | 2 | R11, R19 | 12k1 | Device:R | Resistor_SMD:R_0402_1005Metric_Pad0.72x0.64mm_HandSolder | ~ |  |  | Yageo | RC0402FR-0712K1L
18 | 2 | R12, R20 | 5k11 | Device:R | Resistor_SMD:R_0402_1005Metric_Pad0.72x0.64mm_HandSolder | ~ |  |  | Yageo | RC0402FR-075K11L
19 | 2 | R14, R22 | 200 | Device:R | Resistor_SMD:R_0402_1005Metric_Pad0.72x0.64mm_HandSolder | ~ |  |  | Yageo | RC0402FR-07200RL
20 | 3 | R15, R23, R24 | 100 | Device:R | Resistor_SMD:R_0402_1005Metric_Pad0.72x0.64mm_HandSolder | ~ |  |  | Yageo | RC0402FR-07100RL
21 | 2 | R28, R29 | 0.012 | Device:R_Shunt | twonkie:R_Shunt_Ohmite_LVK12 | https://www.ohmite.com/assets/docs/res_lvk.pdf | LVK12R012FERCT-ND
22 | 1 | SW1 | EVQ-P7M01P | Switch:SW_Push | Button_Switch_SMD:SW_SPST_EVQP7C | http://www.apem.com/int/index.php?controller=attachment&id_attachment=1371 | P16770CT-ND |  | Panasonic | EVQ-P7M01P
23 | 2 | U1, U2 | INA237 | twonkie:INA237 | Package_SO:VSSOP-10_3x3mm_P0.5mm | https://www.ti.com/lit/ds/symlink/ina237.pdf | 296-INA237AIDGSRCT-ND | 0x40 | TI | INA237AIDGSR
24 | 1 | U3 | MIC5504 | Regulator_Linear:MIC5504-3.3YM5 | Package_TO_SOT_SMD:SOT-23-5_HandSoldering | https://www.analog.com/media/en/technical-documentation/data-sheets/AD8610_8620.pdf | 576-4764-1-ND |  | Microchip | MIC5504-3.3YM5-TR
25 | 1 | U4 | STM32F072CB | MCU_ST_STM32F0:STM32F072CBTx | twonkie:LQFP-48_7x7mm_P0.5mm-QFN48-Frankenstein | http://www.st.com/st-web-ui/static/active/en/resource/technical/document/datasheet/DM00090510.pdf | 497-18747-1-ND |  | STMicro | STM32F072CBT
26 | 1 | U5 | AD8606 | Amplifier_Operational:AD8620 | Package_SO:MSOP-8_3x3mm_P0.65mm | https://www.analog.com/media/en/technical-documentation/data-sheets/AD8610_8620.pdf | 505-AD8606ARMZ-R7CT-ND |  | Analog Devices | AD8606ARMZ-R7

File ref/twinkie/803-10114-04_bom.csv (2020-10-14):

TITLE: Bill of Materials
DATE: 1/09/2015
DESIGN: twinkie
APN: 803-10114-04
REV: 0.00
S.No. | Qty | Ref Des | Manufacturer | Manufacturer PN | Description
1 | 1 | C8 | AVX | 0201ZD103KAT2A | CAP-10NF-10V-X5R-10%-0201
2 | 3 | C4-C6 | TDK | C0603X5R1A104K030BC | CAP-100NF-10V-X5R-10%-0201
3 | 2 | C2,C3 | TDK | C1005X5R1A475M050BC | CAP-4.7UF-10-X5R-20%-0402
4 | 2 | C1,C7 | TDK | C0603X5R0J105M030BC | CAP-1UF-6.3V-X5R-20%-0201
5 | 2 | R7,R8 | PANASONIC | ERJ1GEF1212C | RES-12.1K-1%-0.050W-0201
6 | 2 | R3,R4 | PANASONIC | ERJ1GEF4751C | RES-4.75K-0.050W-0201
7 | 2 | R14,R16 | PANASONIC | ERJ1GEF1000C | RES-100-0.050W-0201
8 | 2 | R13,R15 | PANASONIC | ERJ1GEF2000C | RES-200-0.050W-0201
9 | 2 | R20,R27 | PANASONIC | ERJ1GEF5760C | RES-576-1%-0.050W-0201
10 | 2 | R21,R28 | PANASONIC | ERJ1GEF6040C | RES-604-1%-0.050W-0201
11 | 2 | R19,R26 | PANASONIC | ERJ1GEF8060C | RES-806-1%-0.050W-0201
12 | 2 | R5,R6 | PANASONIC | ERJ1GEF1001C | RES-1K-1%-0.050W-0201
13 | 2 | R24,R25 | PANASONIC | ERJ1GEF2211C | RES-2.21K-1%-0.050W-0201
14 | 2 | R9,R10 | PANASONIC | ERJ1GEF5111C | RES-5.11K-1%-0.050W-0201
15 | 2 | R11,R12 | PANASONIC | ERJ1GEF3572C | RES-35.7K-1%-0.050W-0201
16 | 2 | R22,R23 | PANASONIC | ERJ1GEF5112C | RES-51.1K-1%-0.050W-0201
17 | 2 | R17,R18 | PANASONIC | ERJ1GEF3013C | RES-301K-1%-0.050W-0201
18 | 2 | R1,R2 | CYNTEC | RL1632L4-R015-DN | Res-Sense-15mOhm-0.5%-1W-150ppm-RS1206_4P
19 | 2 | FB1,FB2 | MURATA | BLM15AG601SN1D | IND-FERR-BEAD-600OHM@100MHZ-0402
20 | 2 | U1,U2 | TI | INA231AIYFFR | IC, High or Low-side Bidirectional Current/Power Monitor with 1.8V I2C, 0.4mm BGA12
21 | 1 | U4 | ST MICRO | STM32F072CBY6 | IC, Microcontroller, ARM Cortex M0, 128k Flash, Low power, 2.0-3.6V, 3.3x3.1mm, WLCSP49
22 | 1 | U5 | ANALOG | AD8606ACB | OpAmp-Rail-To-Rail-Dual-BW=10Mhz-VOS=300uV-DUAL_WLCSP8
23 | 1 | U3 | MICREL | MIC5504-3.3YMT | IC, LDO, 300mA, VIN=-0.3-6V, VOUT=3.3V, VDO=160mV, Cout(min)=1uF, En, DFN4
24 | 1 | CN1 | MOLEX | 47642-0001 | CONN, USB, SINGLE, TYPE-MICRO-B, RECEP, MID-MOUNT, SMT
25 | 1 | J1 | FOXCONN | UT00113-10006-4H | CONN, USB3.0, SINGLE, TYPE-C, NEWARK/MUXED, PLUG, STRADDLE-MOUNT, SMT, SNIFFER PINOUT
26 | 1 | J2 | FOXCONN | UT12123-1A5BA-7H | CONN, USB3.0, SINGLE, TYPE-C, NEWARK/MUXED, RECEP, RA, dual-row, mid mount, SMT
27 | 2 | DS1,DS2 | ROHM | SMLP34RGB2W | RGB common anode, top firing low profile
28 | 3 | Q1-Q3 | NXP | PMDXB600UNE | Dual N-channel Trench MOSFET
29 | 1 | D1 | DIODES INC | BZT52C5V6LP-7 | Diode, zener, 250mW, 5.6V,0402
30 | 1 | Q4 | TI | CSD13381F4 | NMOS-12V-2.1A-225mOhm-0402
TOTAL | 53

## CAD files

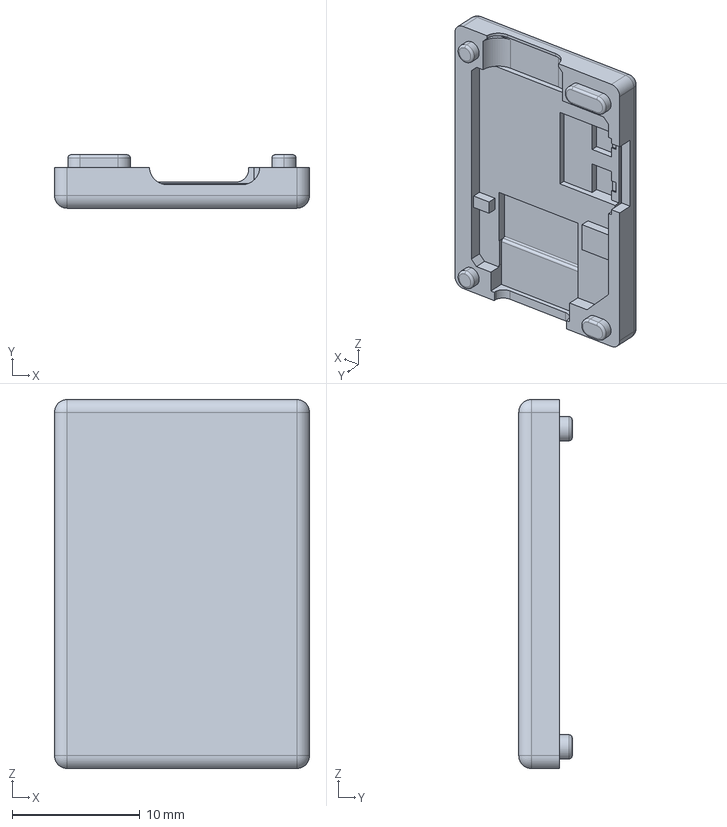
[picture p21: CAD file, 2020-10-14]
ref/twinkie/0000045244_Housing_Top.stp
20.0 x 4.20 x 28.9 mm

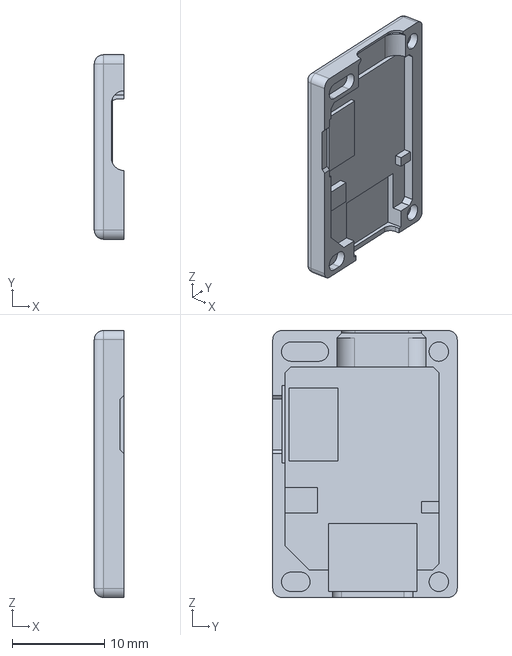
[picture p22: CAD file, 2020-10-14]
ref/twinkie/0000045262_Housing_bottom.stp
3.20 x 20.0 x 28.9 mm

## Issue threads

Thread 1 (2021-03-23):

Purpose of discontinuous CC2?

henryrgithub, 2021-03-23:
I'm confused as to the purpose of having a discontinuous CC2 on the board. Do you have to ensure correct cable orientation between Twonkie, the host and the device? On first blush it looks like twisting the cable could leave no CC line between the device and the host.

dojoe, 2021-03-23:
CC2 isn't discontinuous, it's just taken through a voltage/current monitor device; the INA260 has an internal shunt resistor for monitoring current so the signal goes right through it.

Depending on plug orientation either CC1 or CC2 is used for the actual control channel, and the other line becomes VCONN, the supply voltage for active circuitry in the plugs and/or cable. With the INA260 on one of the CC lines Twonkie is able to monitor VCONN voltage and current in one of the two orientations. Control channel communication will work in either orientation since both lines are continuous (modulo a very low value shunt resistor).

Does this help clear up your confusion? :)

henryrgithub, 2021-03-23:
Ah yes, that makes sense! Thanks for the clarification.

Closed 2021-03-23.

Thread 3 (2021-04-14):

Microcontroller part number is ambiguous

kristinpaget, 2021-04-14:
In the microcontroller part in the schematic, the field "Mfg P/N" is listed as "STM32F042C6T6TR" with a library reference of "STM32F042C6Tx" and a value of "STM32F072CB".  The BoM in hw/v1.0/twonkie.bom.csv reflects this as well, even the Digikey P/N points to the F042.  It would be preferable to switch to the STM32F072CBTx library part and P/Ns so that all four fields can remain consistent; I didn't notice the discrepancy until I tried to flash my otherwise fully-assembled units and realised I'd bought the wrong uC's.

dojoe, 2021-04-14:
Oh crap - unit**s** even 😬 I'm very sorry about that! Hope it's not too much work to fix :/

That's a remnant from when I thought I could pull this off with an F042 - until Vincent made me aware they're using some of the F072's features which the F042 doesn't have. So I changed the value and called it a day, didn't even notice I had misleading part numbers all over the place.

I updated the schematics and BOM - thanks for reporting!

Closed 2021-04-14.

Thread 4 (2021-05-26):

EPR support

dnschneid, 2021-05-26:
Unfortunately, the INA260 only goes up to 36V (and will pop above 40V).  The new EPR standard goes up to 48V.

I don't see any TI INAs that do the higher voltage with integrated sense resistors, unfortunately.

dojoe, 2021-05-28:
Dang, too bad. Looks like I should replace the INA260 by an INA237 and an external shunt then. There goes my 1"x1" envelope 😭
Before I go and rip the layout apart, can you think of anything else that would cause problems with recent PD developments - such as the F072CB eventually being unable to host a firmware capable of decoding the byzantine PD protocols?

dnschneid, 2021-05-28:
The F072CB is fine if you're using sigrok/pulseview to decode stuff, since it's just passing along the bits.

dojoe, 2023-01-29:
Well, that took a while -.-
I've got a beta v2.0 layout now that sports the INA237 and still fits the 1in by 1in envelope :)
Would you be willing to take a glance at 59ddbe225d1126198d7e3ff15a19b13e037b3664 and point out any glaring mistakes? The bottom half of the board hasn't changed but the top half has. I'm mostly worried about the current carrying capabilities of the VBUS copper planes, and perhaps the odd trace/via snuggling up too closely to the high speed traces.

dnschneid, 2023-02-02:
The layout looks pretty good!  VBUS current capacity seems totally fine; you have two planes (effectively) and plenty of vias per pin.

Just comments/nits here:

 * You have the sense resistors set up for diagonal conduction.  I assume this is to make layout a little easier, but the datasheet recommends conducting on one side and sensing on the other.  I have no idea how the device is constructed so my best guess is that accuracy could suffer.  Honestly the part is a little weird -- I'd have expected a dedicated kelvin sense resistor to be asymmetric to reduce the conduction losses at the solder joint, but maybe the part is just too small to do that and still be easily assembled.
 * I'm also a little surprised you swapped out the Vconn sense as well; the old one would have worked just fine.  I suppose it makes the firmware easier though, as does keeping the same sense resistor value.  I don't remember what we did on Twinkie since the chromium.org site seems to be borked and not showing attachments anymore.
 * You could make VRCONN+ hug the +3V3 trace on inner2 and let vbus or gnd flood the remainder.
 * You may also want to connect the VBUS_RECEP shape on inner2 connect with the vias just north of them.
 * 48V is the point at which you may want to consider spacing requirements.  IPC-2221B says 4 mils (0.1mm) on internal layers and 24 mils (0.6mm) on external layers.  I'm not sure you really need to follow that spec for a testing device that's not on all the time, so if those constraints mess up your layout I wouldn't bother.
 * Nice job squeezing the D+/D- between the sense resistor leads :wink:  Maybe shove the left half down a smidge to center the pair between CC1 and SBU1.
 * RX2 is definitely cramped.  Not much I can recommend that wouldn't result in a big rip-up,  as far as I can tell.  The proximity of the SBU1 trace is the worst offender, so if there's anywhere else you can route that, that may be worthwhile.  I can see adding a via on the right side to route it next to SBU2, but after that it gets pretty hairy.  This is an impressively dense layout!

dojoe, 2023-02-04:
Thanks for the thorough review! Applying your suggestions turned out to be easier than expected :)
I updated the `epr` branch with an updated layout.

> You have the sense resistors set up for diagonal conduction.  I assume this is to make layout a little easier, but the datasheet recommends conducting on one side and sensing on the other.

I blame that one on the KiCad footprint library ;) Well spotted, thank you!
Turns out that this is relatively easy to fix if I rotate the VBUS sense resistor by 90 degrees and the result looks a lot better :)

>  I'm also a little surprised you swapped out the Vconn sense as well; the old one would have worked just fine.

I don't remember my rationale for that but I guess part of it was BOM reduction - why depend on two different pieces of Unobtainium when you could depend on one instead? ;)

>  You could make VRCONN+ hug the +3V3 trace on inner2 and let vbus or gnd flood the remainder.

The goal being less board area to etch, correct? Makes sense to me - I generally tried to grow all pours where easily possible now.

>  You may also want to connect the VBUS_RECEP shape on inner2 connect with the vias just north of them.

My thinking was to separate the current flow originating from the top and bottom pair of VBUS pins to evenly spread the load between the planes, I guess I was overthinking things there and should just let the electrons do their thing? :)

>  48V is the point at which you may want to consider spacing requirements.  IPC-2221B says 4 mils (0.1mm) on internal layers and 24 mils (0.6mm) on external layers.

Wouldn't the Twonkie fall more into class B4 due to the solder mask though, making the clearance requirement for outer layers 5 mils / 0.13mm?
I'm currently at 6 mils in my DRC setup so B4 would be satisfied. I'm not sure I could even escape the Type-C connector at 24mil spacing 😅

>  Nice job squeezing the D+/D- between the sense resistor leads 😉  Maybe shove the left half down a smidge to center the pair between CC1 and SBU1.

Yup, and it looks nicer too :)

>  RX2 is definitely cramped.

There was still some space above the sense resistor to move it up a smidge, so I could move SBU1 away from RX2. Now VCONN_ALERT_L and that 3V3 via are the worst offenders but those aren't going to budge :)

> This is an impressively dense layout!

Thank you 😊

dnschneid, 2023-02-05:
I honestly have no idea for the 48V stuff, so your conclusion is as good as mine :)

Fixes look great!

dojoe, 2023-02-06:
Alright, let's see how the board behaves once I get them back from OSHPark! Thanks again for the review!

dojoe, 2023-06-11:
Well, it took me only two years but it's done now :) The prototype works and the firmware supports the INA237 as of today's release: https://github.com/dojoe/Twonkie/releases/tag/twonkie-20230611
I merged the EPR development branch into master now - I think the hardware is fine and the firmware supports all the basic stuff.

Long term I'd like to add a few more bells and whistles but those are separate items :)

Closed 2023-06-11.

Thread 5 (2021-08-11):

Links to Parts

volatileConst, 2021-08-11:
Hi, I am a noob trying to solder and replicate the Twonkie.

I was wondering how to read the schematic and determine where to buy the parts apart from the wafer?

Thank you.

dojoe, 2021-08-14:
Hi! :)

The KiCad schematic file contains the vendor part numbers and DigiKey order numbers for each part designator, and I exported the full list into a .csv file too - those are commonly called "Bill of materials" or BOM for short, and this is the one for Twonkie 1.0: https://github.com/dojoe/Twonkie/blob/master/hw/v1.0/twonkie.bom.csv. You should be able to punch those part numbers into a parts supplier of your choice (I usually use DigiKey but there are plenty others) to find the parts you need. If they have parts in stock they'll happily sell you small quantities, though at an increased price. Take care to order more of most parts than you need - especially the tiny passives (resistors, capacitors...) are easy to lose during assembly.

As for reading the schematic, it probably helps to have some familiarity with USB-PD and the [original project description](https://www.chromium.org/chromium-os/twinkie), and then read up on the [device datasheets](https://github.com/dojoe/Twonkie/tree/master/ref) to understand which part does what.

Having said all that, please be warned that the Twonkie is not exactly a noob project - unless you're already familiar with hand-soldering fine pitch SMT parts you may be in for a frustrating experience. Don't let that keep you from trying, but you should know what you're signing up for :)

volatileConst, 2021-08-16:
Thank you for the thoughtful comments.

Yes, I noticed that soldering will be a challenge, especially with everything being surface-mounted. I just ordered parts from Digikey. However, due to backordering time and my school semester starting soon, I will probably not have time for this once until the semester is over.

As for closing the issue, I will close it once I start on the project itself and feel like I have no large questions left if that is good with you.

dojoe, 2023-02-04:
This issue's been lingering for a while now, so I'm going to close it. I moved my explanation into the README file so other can benefit from it as well. Once you get around to starting the project and have further questions feel free to open a new issue!

Closed 2023-02-04.

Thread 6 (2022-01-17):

J2/EDAC_690-024-294T331_EdgeMount  Obsolete and no longer in stock

johnreitan, 2022-01-17:
What is a good replacement for EDAC_690-024-294T331_EdgeMount (151-1601-1-ND)?
Digikey suggests USB4070-30-C (2073-USB4070-30-CCT-ND) as a replacement, is this ok?

dojoe, 2022-01-17:
Yes, I've ordered and tested that part for a build last year and it's a good replacement. I'll update the KiCad files and BOM.

dojoe, 2023-02-04:
I updated the part number now - sorry it took so long. Once the `epr` branch gets merged this will show up in master too.

Closed 2023-02-04.

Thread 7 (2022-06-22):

A sensor is out of stock

danielzfranklin, 2022-06-22:
The part [INA260AIPWR](https://www.digikey.com/en/products/detail/texas-instruments/INA260AIPWR/6590780) is out of stock on DigiKey and Mouser. Mouser lists the estimated restocking time as a bit less than a year.

Based on github activity I suspect you aren't currently updating this project. If you are, I thought this might be useful.

dnschneid, 2022-06-22:
A lot of components are out of stock right now.  You may be able to find it with an alternative supplier, such as one listed in [Octopart](https://octopart.com/ina260aipwr-texas+instruments-75199489?r=sp) (see the non-authorized category).

dojoe, 2022-06-22:
I am working on replacing the INA260 with an INA237 in the background, but since that requires an external shunt I am running into a lot of routing issues, and I don't have much time to devote to fixing those (and growing the board is out of the question, I have my principles! ☝️ ). One day! ;)

danielzfranklin, 2022-06-22:
Thanks everyone. (I'm assuming the $50-$90 per is the plausible price, and the $4-$10 is definitely a scam @dnschneid.)

dnschneid, 2022-06-22:
[MSRP from TI](https://www.ti.com/product/INA260/part-details/INA260AIPWR) is $4 in single unit quantities, so the larger numbers you're seeing are due to scalping.

gidoBOSSftw5731, 2022-09-10:
Sorry to use an old thread but the part is still wildly out of stock and, although I have sent in RFQ to a few distributors on octopart, I'm not super optimistic. Is there another chip that could work instead? Could a board redesign happen somehow? (I work in software not circuits usually so I don't really know how hard that would be)

dojoe, 2022-09-10:
No worries, I mean it's not like the shortage problem has been resolved by now :) I _have_ started designing an updated Twonkie that uses the INA237, mainly to resolve #4, but it's an on-and-off effort and pretty tricky to fit into the tight 1in x 1in envelope I have set myself, so I have not been successful yet. That said, your post might give me the motivation I need to take another crack at it :)

dojoe, 2022-09-10:
(fwiw the 237 is also out of stock but at least mouser claims having some incoming in november 😅 )

gidoBOSSftw5731, 2022-09-10:
I was taking a poke at https://github.com/gregdavill/PD-sniffer and the chip they use (an INA321 I think) isn't backordered, if that's of any use to you. I don't think it would solve the voltage issue in #4 but being able to test things before 2024Q4 (which was one estimate I got lol) would be nice.

dojoe, 2023-02-04:
If it's any help, I am making a lot of progress on #4 and at the time I'm typing this DigiKey actually have a few of the 237s in stock :) The INA228 and INA238 appear to be possible drop-in replacements for the 237 too, and Mouser has a bunch of the 228 incoming in April.
Oh, and Mouser has 30 INA260s in stock right now, so if you're quick you may get lucky :)

dojoe, 2023-06-11:
Twonkie v2 is out now, with an INA237 which has two compatible drop-in replacement parts.

Closed 2023-06-11.

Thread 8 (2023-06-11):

Non-EPR hardware protection

dojoe, 2023-06-11:
Detect EPR voltages on Twinkie and Twonkie v1 hardware, force the source to turn off to protect the voltage monitor chips.

Options:
 * Sniff PD negotiation and detect EPR voltages being negotiated; inject control channel states that will abort the negotiation if so.
   * Pro: Prevents dangerous voltages completely
   * Con: Hard to implement, firmware might miss packets and thus not trigger
 * Set INA up to alert above 24V, immediately react in the interrupt handler by forcing the control channels into an invalid/reset state (possible?)
   * Pro: Easier implementation
   * Con: May be too late to protect the chips 💥

dojoe, 2023-06-11:
Prerequisite: EPR capable source and sink for testing

FCALLBOX, 2024-04-18:
hi Dojoe,
I am a little bit confused about the USB-C work when the the source are asking for 9V or 15V or 20V, the V2 HW cannot support such voltages as there is a zener 5V6 on VBUS and that the LDO MC5504 can only work at 5.5V max.

FCALLBOX, 2024-04-18:
So If I understand you does not allow USB-C negotiation over 5V ?

dojoe, 2024-04-27:
Hey @FCALLBOX!
The diode and vreg are on the analyzer logic supply which is always 5V, provided via the Micro-B receptacle by the controlling PC. The USB-C voltages are only observed via the INAxxx chips, they don't power anything on the board.
Does this help?

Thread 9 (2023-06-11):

Decode EPR messages in internal trace

dojoe, 2023-06-11:
Given an EPR capable source and sink, sniff their communication with internal trace enabled and check that the EPR messages are decoded correctly.

Prerequisite: EPR capable source and sink

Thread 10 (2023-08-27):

Improved USB connectors

XenGi, 2023-08-27:
Ohai!

I created a 2.1 version of the twonkie with better USB-C connectors. Have a look and maybe merge it back if you like: https://gitlab.com/XenGi/Twonkie

I also added a 3D printable case which fits very nicely and uploaded it too: https://www.printables.com/model/562407-twonkie-v21-case

dojoe, 2023-08-27:
Hey, wow, that's awesome! Thanks for the change and the great case! :)

There's a problem however: Those straddle mount connectors only work for 0.8mm boards - the main reason for my weird connector setup is that it works with 1.6mm boards which are cheap and widely available. In fact the very first v0.9 of Twonkie was built for those straddle mount connectors until I realized they wouldn't work with 1.6mm boards.

Do you have a good overview over how easy it is to find a board house that will make 0.8mm 4layer boards in small quantities for cheap? That wasn't really an option back when I started the project, and I wouldn't like for Twonkie boards to be manufacturable by the likes of JLCPCB only - that would go against the original idea for me.

If pretty much any board house can make thin 4layer boards for cheap these days I'm with you that those straddle connectors are clearly better and easier to solder. If not however I'd rather stick with the current connector design.

As for the case, I'll give it a whirl and see how well it fits my Twonkies :)

Thanks again and let me know what you think!

XenGi, 2023-08-28:
I'll check with PCB fabs. I created this design kind of in a hurry to have it before CCC camp.

dnschneid, 2023-08-28:
I found that without really solid overmolding (or maybe a metal bucket-style enclosure), 0.8mm thick PCBs with a straddle mount connector made for a really weak Twinkie.  It's definitely the thing that fails first -- there's just too much torque on that mounting point.

XenGi, 2023-08-29:
So I did some research.

- [PCBWay](https://www.pcbway.com/):
  - 5 PCBs with HASL: $ 29.61
  - 5 PCBs with ENIG: $ 59.83
- [JLCPCB](https://jlcpcb.com/):
  - 5 PCBs with HASL: $ 7.00
  - 5 PCBs with ENIG: $ 17.60
- [NextPCB](https://www.nextpcb.com/)
  - 5 PCBs with HASL: $ 34.31
  - 5 PCBs with ENIG: $ 55.35
- [EuroCircuits](https://www.eurocircuits.com/)
  - 10 PCBs with HASL: € 1000.06
  - 10 PCBs with ENIG: € 1103.40
- [PCBTrain](https://www.pcbtrain.co.uk/)
  - 5 PCBs with HASL:  £ 293.95
  - 5 PCBs with ENIG: £ 323.45

I would say there are quite some options where you could get this done. I honestly don't know many other PCB fabs outside China because I'm usually not willing to pay the premium price for small quantity prototypes.
[Oshpark](https://oshpark.com/) sadly only does 2 layer 0.8mm and [Aisler](https://aisler.net/) is looking into offering 0.8mm boards in the future but at the moment you can only get them when you do a custom order for assembled boards.

hpo14, 2023-11-16:
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

it would be nice if you can provide some simulate pics with the new USB-C connector,

XenGi, 2023-11-18:
Sure, Ill add some when I get to it.

dojoe, 2023-11-25:
I've given this some thought and what @dnschneid wrote makes me think the Twonkie better stay at 1.6mm. With the shell soldered to the PCB those connectors are _on_ there, no case required for stability. So while the connector mount method is certainly haxxy I prefer it over the standard 0.8mm straddle mount connectors.

Plus your cost breakdown seems to indicate that moving to 0.8mm would pretty much lock people into PCBWay or JLCPCB. I prefer leaving options open where possible and affordable four-layer boards still seem to be more widely available in 1.6mm.

I'll put a link to your repo into my readme however, so people looking for a 0.8mm variant or one with a case can easily find yours - thanks for providing it!

Closed 2023-11-25.

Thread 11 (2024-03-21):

Inconsistent I2C address of the VCONN INA237 + CC1/CC2 connection

Hueburtsonly, 2024-03-21:
Firstly, thanks so much for designing this board -- I especially appreciate the enhancements over the original Twinkie with higher supported VBUS and dedicated BOOT pushbutton!

1. The VCONN INA237 has both A0 and A1 pulled up to 3V3 -- according to the [INA237 datasheet](https://www.ti.com/lit/ds/symlink/ina237-q1.pdf), this would give an I2C address of 1000101, i.e. 0x45 -- but the schematic labels the chip as 0x43. Is this just a typo on the schematic, or am I misunderstanding something?
2. In any case, the original Twinkie* uses an address of 0x41 for the VCONN INA237 -- just wondering why this was changed to 0x43/0x45 in your design?
3. Similarly, the chip is monitoring CC2 (pin B5) in the original Twinkie, but CC1 (pin A5)  in your design -- again, I understand that it's a bit of an arbitrary decision given the flippability of USB-C, but just curious if I'm missing any further context for this design choice (or if it is somehow connected to the address change above?)

Thanks again!

\* The hardware design for the original Twinkie is actually still available btw, even though the link to it was deleted from the Chromium page: https://www.chromium.org/chromium-os/twinkie/chromium-os-twinkie-v2.tar.bz2

dojoe, 2024-04-27:
Hey - thanks for the kind words and sorry about the late response :/

1. Yep, it's a typo - the code uses 0x45 on v2: https://github.com/dojoe/Twonkie/blob/master/fw/board/twinkie/board.c#L64 - I'll fix the schematic, thanks for noticing!
2. That area of the board is pretty jammed, and pulling both pins the same way needed one less via :)
3. I honestly don't remember any more :) It might have been easier to route for some reason but it might just as well have been arbitrary when I reimplemented the original schematic.

Also I did mirror those hardware files into this repo when I started the project, so they're safe :) See https://github.com/dojoe/Twonkie/tree/master/ref/twinkie

Closed 2024-04-27.

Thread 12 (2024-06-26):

Question on general function

rsend, 2024-06-26:
Hi,
This is pretty cool. I've been looking for an inline sink capable device to enhance my Thunderbolt-in-a-Thinkpad implementation, since it doesn't have any kind of sink capability.

Now, I don't fully understand how this works. If you plug it into a host which itself supports PD-sourcing to some extent (for example, a Thunderbolt port) and then you also plug in, say, a Thunderbolt dock that can charge, which side does this device negotiate power from?

I may be missing something  but it seems as though it could conceivably do both - but that doesn't make sense.

Thanks,
R

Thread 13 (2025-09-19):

Add a note that the OSH-Park link takes to v1

shiona, 2025-09-19:
I didn't due my due diligence and just followed the easy link to OSHPark to order my PCBs, ordered the BOM from Digikey and now that I have both I realized my mistake.

I have components for v2 and PCBs for v1.

Closed 2025-09-20.

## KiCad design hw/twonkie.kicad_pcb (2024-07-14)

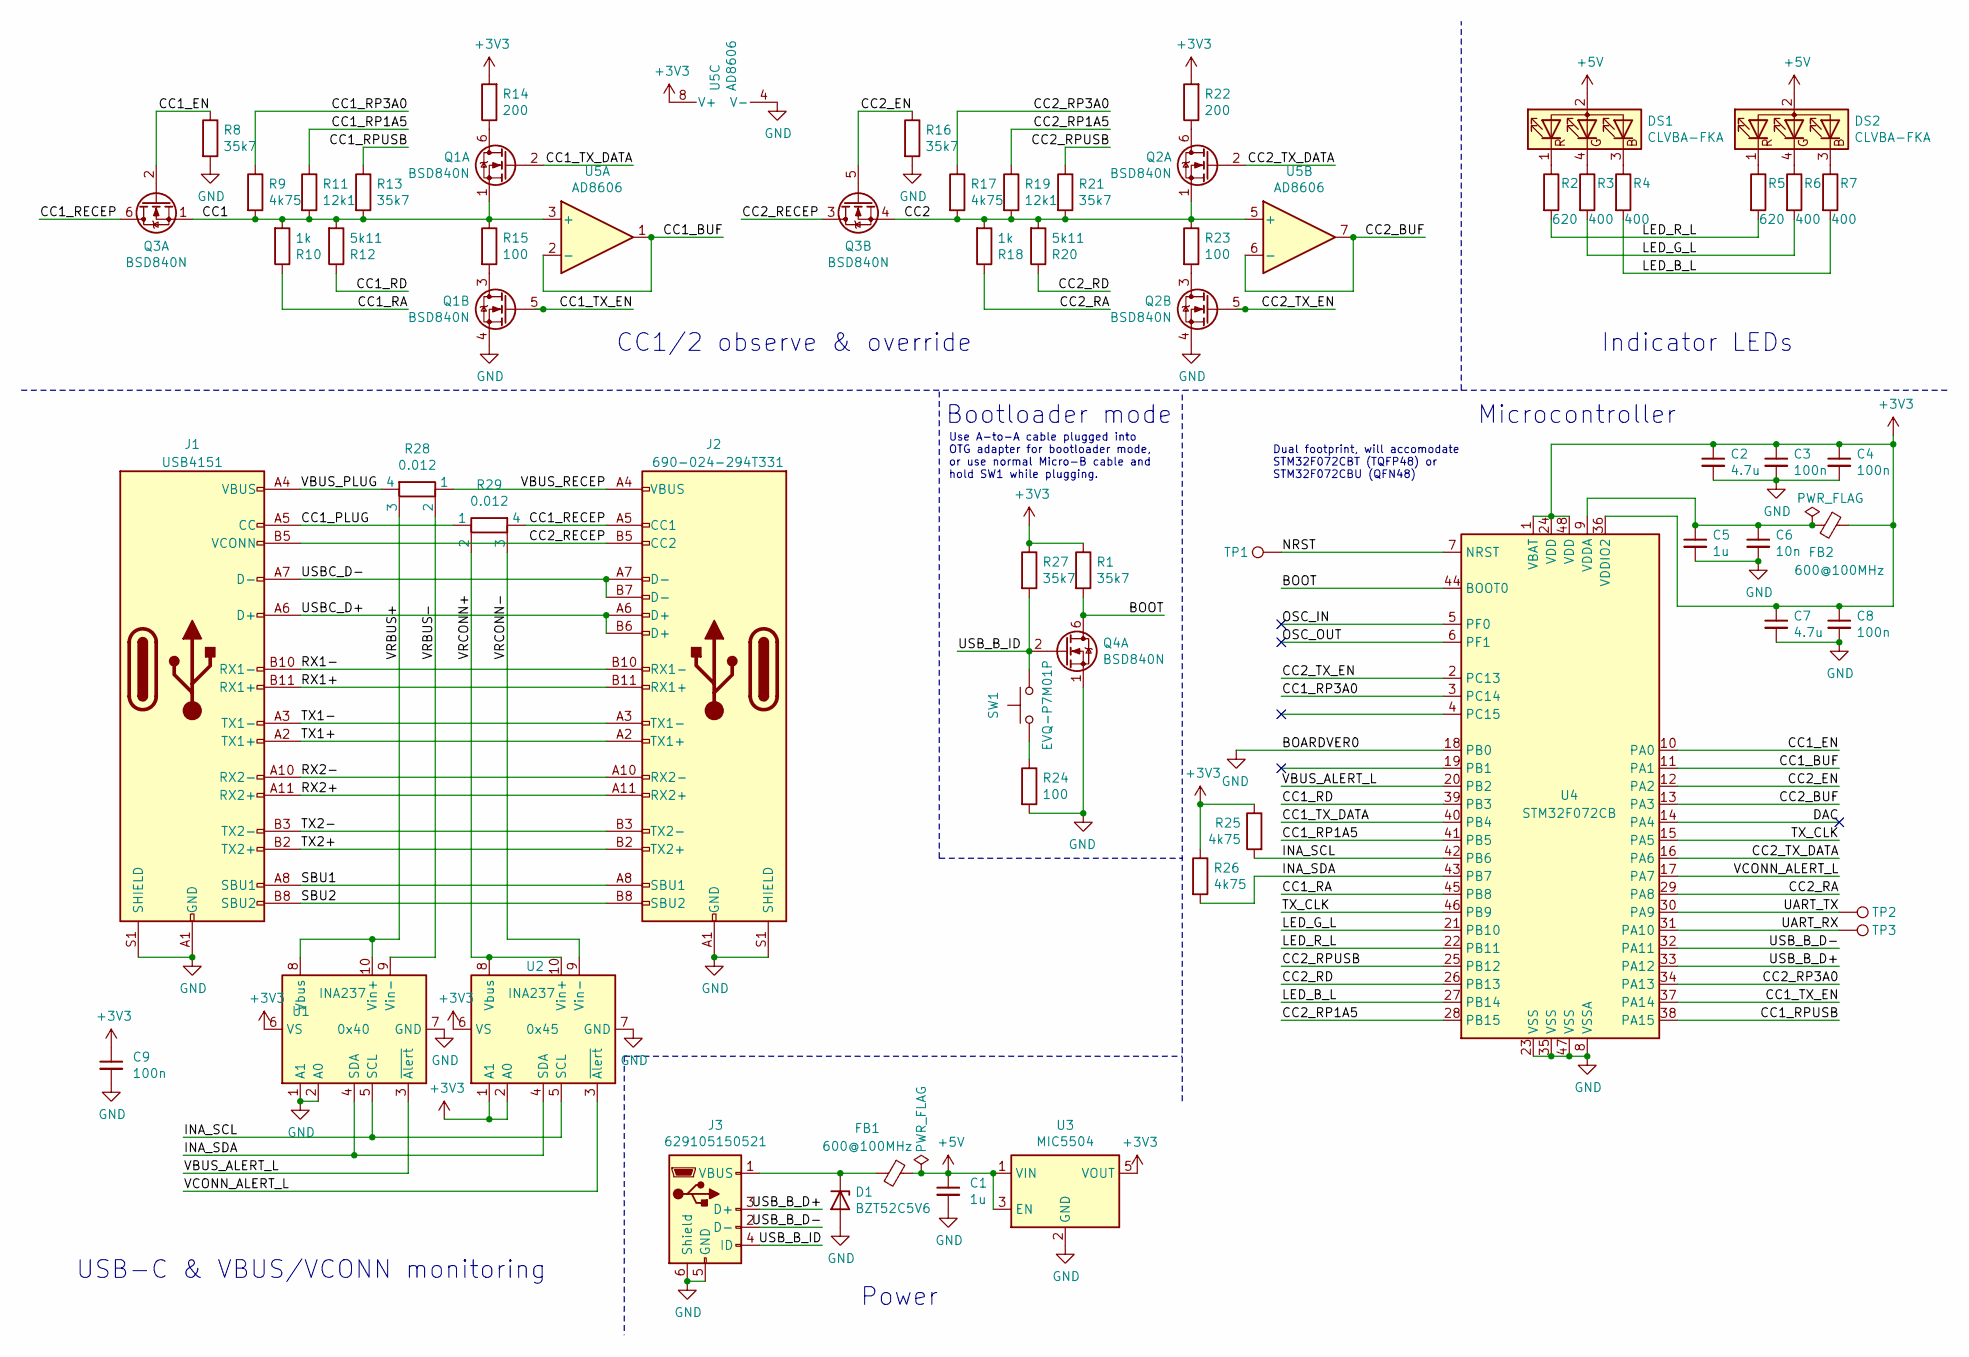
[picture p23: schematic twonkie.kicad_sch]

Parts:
C1, C5: 1u; C_0402_1005Metric_Pad0.74x0.62mm_HandSolder; Mfg P/N CL05A105MQ5NNNC; DigiKey P/N 1276-1235-1-ND
C2, C7: 4.7u; C_0402_1005Metric_Pad0.74x0.62mm_HandSolder; Mfg P/N CL05A475KQ5NRNC; DigiKey P/N 1276-1481-1-ND
C3, C4, C8, C9: 100n; C_0402_1005Metric_Pad0.74x0.62mm_HandSolder; Mfg P/N CL05B104KA5NNNC; DigiKey P/N 1276-6720-1-ND
C6: 10n; C_0402_1005Metric_Pad0.74x0.62mm_HandSolder; Mfg P/N CL05B103KB5NNNC; DigiKey P/N 1276-1028-1-ND
D1: BZT52C5V6; D_SOD-123; Mfg P/N BZT52C5V6-13-F; DigiKey P/N BZT52C5V6-13-FDICT-ND
DS1, DS2: CLVBA-FKA; LED_Cree-PLCC4_3.2x2.8mm_CCW; Mfg P/N CLVBA-FKA-CAEDH8BBB7A363; DigiKey P/N CLVBA-FKA-CAEDH8BBB7A363CT-ND
FB1, FB2: 600@100MHz; L_0402_1005Metric_Pad0.77x0.64mm_HandSolder; Mfg P/N BLM15AG601SN1D; DigiKey P/N 490-1006-1-ND
J1: USB4151; GCT_USB4151_EdgeMount; Mfg P/N USB4151-GF-C; DigiKey P/N 2073-USB4151-GF-CCT-ND
J2: 690-024-294T331; EDAC_690-024-294T331_EdgeMount; Mfg P/N USB4070-30-C; DigiKey P/N 2073-USB4070-30-CCT-ND
J3: 629105150521; USB_Micro-B_Wuerth_629105150521_HandSolder; Mfg P/N 629105150521; DigiKey P/N 732-5960-1-ND
Q1, Q2, Q3, Q4: BSD840N; SOT-363_SC-70-6; Mfg P/N BSD840NH6327XTSA1; DigiKey P/N BSD840NH6327XTSA1CT-ND
R1, R8, R13, R16, R21, R27: 35k7; R_0402_1005Metric_Pad0.72x0.64mm_HandSolder; Mfg P/N RC0402FR-0735K7L
R2, R5: 620; R_0402_1005Metric_Pad0.72x0.64mm_HandSolder; Mfg P/N RC0402FR-07620RL
R3, R4, R6, R7: 400; R_0402_1005Metric_Pad0.72x0.64mm_HandSolder; Mfg P/N RC0402FR-07402RL
R9, R17, R25, R26: 4k75; R_0402_1005Metric_Pad0.72x0.64mm_HandSolder; Mfg P/N RC0402FR-074K75L
R10, R18: 1k; R_0402_1005Metric_Pad0.72x0.64mm_HandSolder; Mfg P/N RC0402FR-071KL
R11, R19: 12k1; R_0402_1005Metric_Pad0.72x0.64mm_HandSolder; Mfg P/N RC0402FR-0712K1L
R12, R20: 5k11; R_0402_1005Metric_Pad0.72x0.64mm_HandSolder; Mfg P/N RC0402FR-075K11L
R14, R22: 200; R_0402_1005Metric_Pad0.72x0.64mm_HandSolder; Mfg P/N RC0402FR-07200RL
R15, R23, R24: 100; R_0402_1005Metric_Pad0.72x0.64mm_HandSolder; Mfg P/N RC0402FR-07100RL
R28, R29: 0.012; R_Shunt_Ohmite_LVK12; DigiKey P/N LVK12R012FERCT-ND
SW1: EVQ-P7M01P; SW_SPST_EVQP7C; Mfg P/N EVQ-P7M01P; DigiKey P/N P16770CT-ND
TP1, TP2, TP3: TestPoint; TestPoint_Pad_D1.0mm
U1, U2: INA237; VSSOP-10_3x3mm_P0.5mm; Mfg P/N INA237AIDGSR; DigiKey P/N 296-INA237AIDGSRCT-ND
U3: MIC5504; SOT-23-5_HandSoldering; Mfg P/N MIC5504-3.3YM5-TR; DigiKey P/N 576-4764-1-ND
U4: STM32F072CB; LQFP-48_7x7mm_P0.5mm-QFN48-Frankenstein; Mfg P/N STM32F072CBT; DigiKey P/N 497-18747-1-ND
U5: AD8606; MSOP-8_3x3mm_P0.65mm; Mfg P/N AD8606ARMZ-R7; DigiKey P/N 505-AD8606ARMZ-R7CT-ND

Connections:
+3V3: C2.1, C3.1, C4.1, C7.1, C8.1, C9.1, FB2.1, R1.1, R14.2, R22.2, R25.1, R26.1, R27.1, U1.6 (VS), U2.1 (A1), U2.2 (A0), U2.6 (VS), U3.5 (VOUT), U4.1 (VBAT), U4.24 (VDD), U4.36 (VDDIO2), U4.48 (VDD), U5.8 (V+)
+5V: C1.1, DS1.2 (A), DS2.2 (A), FB1.1, U3.1 (VIN), U3.3 (EN)
/BOOT: Q4.6 (D), R1.2, U4.44 (BOOT0)
/CC1: Q1.1 (S), Q3.1 (S), R9.2, R10.2, R11.2, R12.2, R13.2, R15.1, U5.3 (+)
/CC1_BUF: U4.11 (PA1), U5.1, U5.2 (-)
/CC1_EN: Q3.2 (G), R8.1, U4.10 (PA0)
/CC1_PLUG: J1.A5 (CC), R29.1
/CC1_RA: R10.1, U4.45 (PB8)
/CC1_RD: R12.1, U4.39 (PB3)
/CC1_RECEP: J2.A5 (CC1), Q3.6 (D), R29.4
/CC1_RP1A5: R11.1, U4.41 (PB5)
/CC1_RP3A0: R9.1, U4.3 (PC14)
/CC1_RPUSB: R13.1, U4.38 (PA15)
/CC1_TX_DATA: Q1.2 (G), U4.40 (PB4)
/CC1_TX_EN: Q1.5 (G), U4.37 (PA14)
/CC2: Q2.1 (S), Q3.4 (S), R17.2, R18.2, R19.2, R20.2, R21.2, R23.1, U5.5 (+)
/CC2_BUF: U4.13 (PA3), U5.6 (-), U5.7
/CC2_EN: Q3.5 (G), R16.1, U4.12 (PA2)
/CC2_RA: R18.1, U4.29 (PA8)
/CC2_RD: R20.1, U4.26 (PB13)
/CC2_RECEP: J1.B5 (VCONN), J2.B5 (CC2), Q3.3 (D)
/CC2_RP1A5: R19.1, U4.28 (PB15)
/CC2_RP3A0: R17.1, U4.34 (PA13)
/CC2_RPUSB: R21.1, U4.25 (PB12)
/CC2_TX_DATA: Q2.2 (G), U4.16 (PA6)
/CC2_TX_EN: Q2.5 (G), U4.2 (PC13)
/DAC: U4.14 (PA4)
/INA_SCL: R25.2, U1.5 (SCL), U2.5 (SCL), U4.42 (PB6)
/INA_SDA: R26.2, U1.4 (SDA), U2.4 (SDA), U4.43 (PB7)
/LED_B_L: R4.2, R7.2, U4.27 (PB14)
/LED_G_L: R3.2, R6.2, U4.21 (PB10)
/LED_R_L: R2.2, R5.2, U4.22 (PB11)
/NRST: TP1.1, U4.7 (NRST)
/OSC_IN: U4.5 (PF0)
/OSC_OUT: U4.6 (PF1)
/RX1+: J1.B11 (RX1+), J2.B11 (RX1+)
/RX1-: J1.B10 (RX1-), J2.B10 (RX1-)
/RX2+: J1.A11 (RX2+), J2.A11 (RX2+)
/RX2-: J1.A10 (RX2-), J2.A10 (RX2-)
/SBU1: J1.A8 (SBU1), J2.A8 (SBU1)
/SBU2: J1.B8 (SBU2), J2.B8 (SBU2)
/TX1+: J1.A2 (TX1+), J2.A2 (TX1+)
/TX1-: J1.A3 (TX1-), J2.A3 (TX1-)
/TX2+: J1.B2 (TX2+), J2.B2 (TX2+)
/TX2-: J1.B3 (TX2-), J2.B3 (TX2-)
/TX_CLK: U4.15 (PA5), U4.46 (PB9)
/UART_RX: TP3.1, U4.31 (PA10)
/UART_TX: TP2.1, U4.30 (PA9)
/USBC_D+: J1.A6 (D+), J2.A6 (D+), J2.B6 (D+)
/USBC_D-: J1.A7 (D-), J2.A7 (D-), J2.B7 (D-)
/USB_B_D+: J3.3 (D+), U4.33 (PA12)
/USB_B_D-: J3.2 (D-), U4.32 (PA11)
/USB_B_ID: J3.4 (ID), Q4.2 (G), R27.2, SW1.1
/VBUS_ALERT_L: U1.3 (~Alert), U4.20 (PB2)
/VBUS_PLUG: J1.A4 (VBUS), J1.A9 (VBUS), J1.B4 (VBUS), J1.B9 (VBUS), R28.4
/VBUS_RECEP: J2.A4 (VBUS), J2.A9 (VBUS), J2.B4 (VBUS), J2.B9 (VBUS), R28.1
/VCONN_ALERT_L: U2.3 (~Alert), U4.17 (PA7)
/VRBUS+: R28.3, U1.8 (Vbus), U1.10 (Vin+)
/VRBUS-: R28.2, U1.9 (Vin-)
/VRCONN+: R29.2, U2.8 (Vbus), U2.10 (Vin+)
/VRCONN-: R29.3, U2.9 (Vin-)
GND: C1.2, C2.2, C3.2, C4.2, C5.2, C6.2, C7.2, C8.2, C9.2, D1.2 (A), J1.A1 (GND), J1.A12 (GND), J1.B1 (GND), J1.B12 (GND), J1.S1 (SHIELD), J1.S2 (SHIELD), J1.S3 (SHIELD), J1.S4 (SHIELD), J1.S5 (SHIELD), J1.S6 (SHIELD), J2.A1 (GND), J2.A12 (GND), J2.B1 (GND), J2.B12 (GND), J2.S1 (SHIELD), J2.S2 (SHIELD), J2.S3 (SHIELD), J2.S4 (SHIELD), J2.S5 (SHIELD), J2.S6 (SHIELD), J2.S7 (SHIELD), J2.S8 (SHIELD), J3.5 (GND), J3.6 (Shield), Q1.4 (S), Q2.4 (S), Q4.1 (S), R8.2, R16.2, R24.2, U1.1 (A1), U1.2 (A0), U1.7 (GND), U2.7 (GND), U3.2 (GND), U4.8 (VSSA), U4.18 (PB0), U4.23 (VSS), U4.35 (VSS), U4.47 (VSS), U5.4 (V-)
unnamed: C5.1, C6.1, FB2.2, U4.9 (VDDA)
unnamed: D1.1 (K), FB1.2, J3.1 (VBUS)
unnamed: DS1.1 (RK), R2.1
unnamed: DS1.3 (BK), R4.1
unnamed: DS1.4 (GK), R3.1
unnamed: DS2.1 (RK), R5.1
unnamed: DS2.3 (BK), R7.1
unnamed: DS2.4 (GK), R6.1
unnamed: Q1.3 (D), R15.2
unnamed: Q1.6 (D), R14.1
unnamed: Q2.3 (D), R23.2
unnamed: Q2.6 (D), R22.1
unnamed: R24.1, SW1.2

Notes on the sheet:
Use A-to-A cable plugged into OTG adapter for bootloader mode, or use normal Micro-B cable and hold SW1 while plugging.
Dual footprint, will accomodate STM32F072CBT (TQFP48) or STM32F072CBU (QFN48)
Bootloader mode
Indicator LEDs
Power
CC1/2 observe & override
Microcontroller
USB-C & VBUS/VCONN monitoring

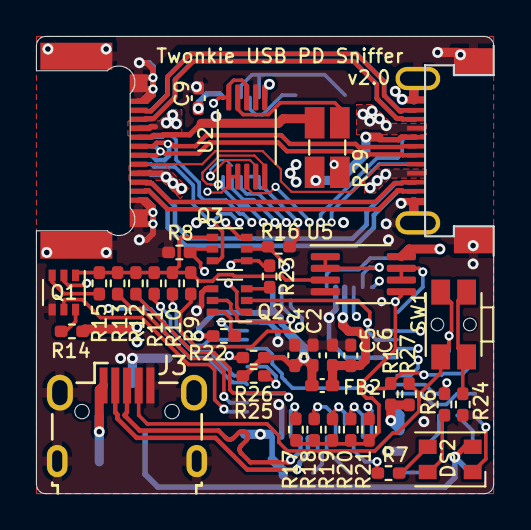
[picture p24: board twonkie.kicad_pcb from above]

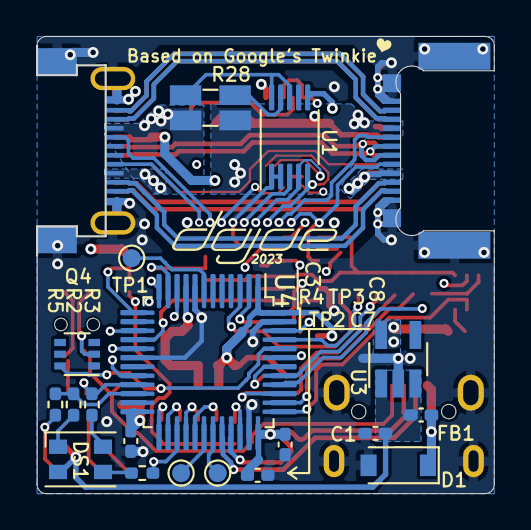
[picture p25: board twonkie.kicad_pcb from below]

Board: 4 copper layers, 25.4 x 25.4 mm, 62 parts (20 on the bottom side), 72 nets.

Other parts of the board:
HEART: (no value)
OSHW_LOGO: oshw_logo_silkscreen_back_3.5mm
dojoe-logo: G***; dojoe-logo

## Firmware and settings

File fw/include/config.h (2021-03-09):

/* Copyright 2016 The Chromium OS Authors. All rights reserved.
 * Use of this source code is governed by a BSD-style license that can be
 * found in the LICENSE file.
 */

/*
 * config.h - Top-level configuration Chrome EC
 *
 * All configuration settings (CONFIG_*) are defined in this file or in a
 * sub-configuration file (config_chip.h, board.h, etc.) included by this file.
 *
 * Note that this file is included by assembly (.S) files.  Any C-isms such as
 * struct definitions or enums in a sub-configuration file MUST be guarded with
 * #ifndef __ASSEMBLER__ to prevent those C-isms from being evaluated by the
 * assembler.
 */

#ifndef __CROS_EC_CONFIG_H
#define __CROS_EC_CONFIG_H

/*
 * All config options are listed alphabetically and described here.
 *
 * If you add a new config option somewhere in the code, you must add a
 * default value here and describe what it does.
 *
 * To get a list current list, run this command:
 *    git grep " CONFIG_" | grep -o "CONFIG_[A-Za-z0-9_]\+" | sort | uniq
 *
 * Some options are #defined here to enable them by default.  Chips or boards
 * may override this by #undef'ing them in config_chip.h or board.h,
 * respectively.
 *
 * TODO(crosbug.com/p/23758): Describe all of these.  Also describe the
 * HAS_TASK_* macro and how/when it should be used vs. a config define.  And
 * BOARD_*, CHIP_*, and CHIP_FAMILY_*.
 */

/*
 * Add support for sensor FIFO:
 * define the size of the global fifo, must be a power of 2.
 */
#undef CONFIG_ACCEL_FIFO

/* The amount of free entries that trigger an interrupt to the AP. */
#undef CONFIG_ACCEL_FIFO_THRES

/*
 * Sensors in this mask are in forced mode: they needed to be polled
 * at their data rate frequency.
 */
#undef CONFIG_ACCEL_FORCE_MODE_MASK

/* Enable accelerometer interrupts. */
#undef CONFIG_ACCEL_INTERRUPTS

/*
 * Support "spoof" mode for sensors.  This allows sensors to have their values
 * spoofed to any arbitrary value.  This is useful for testing.
 */
#define CONFIG_ACCEL_SPOOF_MODE

/* Specify type of accelerometers attached. */
#undef CONFIG_ACCEL_BMA255
#undef CONFIG_ACCEL_KXCJ9
#undef CONFIG_ACCEL_KX022
#undef CONFIG_ACCEL_LIS2DH
#undef CONFIG_ACCELGYRO_LSM6DS0
#undef CONFIG_ACCELGYRO_BMI160
#undef CONFIG_ACCELGYRO_LSM6DSM

/* Specify barometer attached */
#undef CONFIG_BARO_BMP280

/*
 * Use the old standard reference frame for accelerometers. The old
 * reference frame is:
 * Z-axis: perpendicular to keyboard, pointing up, such that if the device
 *  is sitting flat on a table, the accel reads +G.
 * X-axis: in the plane of the keyboard, pointing from the front lip to the
 *  hinge, such that if the device is oriented with the front lip touching
 *  the table and the hinge directly above, the accel reads +G.
 * Y-axis: in the plane of the keyboard, pointing to the right, such that
 *  if the device is on it's left side, the accel reads +G.
 *
 * Also, in the old reference frame, the lid accel matches the base accel
 * readings when lid is closed.
 */
#undef CONFIG_ACCEL_STD_REF_FRAME_OLD

/*
 * Define the event to raise when BMI160 interrupt.
 * Must be within TASK_EVENT_MOTION_INTERRUPT_MASK.
 */
#undef CONFIG_ACCELGYRO_BMI160_INT_EVENT

/* Set when INT2 is an ouptut */
#undef CONFIG_ACCELGYRO_BMI160_INT2_OUTPUT

/* Specify type of Gyrometers attached. */
#undef CONFIG_GYRO_L3GD20H

/*
 * Define the event to raise when LIS2DH  interrupt.
 * Must be within TASK_EVENT_MOTION_INTERRUPT_MASK.
 */
#undef CONFIG_ACCEL_LIS2DH_INT_EVENT

/* Compile chip support for analog-to-digital convertor */
#undef CONFIG_ADC

/*
 * ADC sample time selection. The value is chip-dependent.
 * TODO: Replace this with CONFIG_ADC_PROFILE entries.
 */
#undef CONFIG_ADC_SAMPLE_TIME

/* Include the ADC analog watchdog feature in the ADC code */
#define CONFIG_ADC_WATCHDOG

/*
 * Chip-dependent ADC configuration - select one.
 * SINGLE - Sample all inputs once when requested.
 * FAST_CONTINUOUS - Sample all inputs continuously using DMA, with minimal
 *                   sample time.
 */
#define CONFIG_ADC_PROFILE_SINGLE
#undef CONFIG_ADC_PROFILE_FAST_CONTINUOUS

/*
 * Some ALS modules may be connected to the EC. We need the command, and
 * specific drivers for each module.
 */
#ifdef HAS_TASK_ALS
#define CONFIG_ALS
#else
#undef CONFIG_ALS
#endif
#undef CONFIG_ALS_AL3010
#undef CONFIG_ALS_ISL29035
#undef CONFIG_ALS_OPT3001
/* Define the exact model ID present on the board: SI1141 = 41, SI1142 = 42, */
#undef CONFIG_ALS_SI114X
/* Check if the device revision is supported */
#undef CONFIG_ALS_SI114X_CHECK_REVISION
/*
 * Define the event to raise when BMI160 interrupt.
 * Must be within TASK_EVENT_MOTION_INTERRUPT_MASK.
 */
#undef CONFIG_ALS_SI114X_INT_EVENT
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

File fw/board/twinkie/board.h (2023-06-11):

/* Copyright (c) 2014 The Chromium OS Authors. All rights reserved.
 * Use of this source code is governed by a BSD-style license that can be
 * found in the LICENSE file.
 */

/* Twinkie dongle configuration */

#ifndef __CROS_EC_BOARD_H
#define __CROS_EC_BOARD_H

/* 48 MHz SYSCLK clock frequency */
#define CPU_CLOCK 48000000

/* the UART console is on USART1 (PA9/PA10) */
#define CONFIG_UART_CONSOLE 1

/* Optional features */
#define CONFIG_CONSOLE_PACKETS
#define CONFIG_USB
#define CONFIG_USB_BOS
#define CONFIG_USB_CONSOLE
#define CONFIG_USB_SERIALNO
/* Replaced at runtime (board_read_serial) by chip unique-id-based number. */
#define DEFAULT_SERIALNO ""
#define CONFIG_WEBUSB_URL "twebkie.org"

#define CONFIG_USB_POWER_DELIVERY
#define CONFIG_USB_PD_ALT_MODE
#define CONFIG_USB_PD_ALT_MODE_DFP
#define CONFIG_USB_PD_DUAL_ROLE
#define CONFIG_USB_PD_INTERNAL_COMP
#define CONFIG_USB_PD_PORT_COUNT 1
#define CONFIG_USB_PD_TCPC
#define CONFIG_USB_PD_TCPM_STUB
#define CONFIG_USB_PD_VBUS_DETECT_GPIO
#define CONFIG_PD_USE_DAC_AS_REF
#define CONFIG_HW_CRC

#ifndef HAS_TASK_PD_C0 /* PD sniffer mode */
#undef CONFIG_DMA_DEFAULT_HANDLERS
#define CONFIG_USB_PD_TX_PHY_ONLY
/* override the comparator interrupt handler */
#undef CONFIG_USB_PD_RX_COMP_IRQ
#endif

#define CONFIG_ADC
#define CONFIG_BOARD_PRE_INIT
#define CONFIG_CMD_REBOOT_DFU
#define CONFIG_CMD_USB_PD_PE
#define CONFIG_I2C
#define CONFIG_I2C_MASTER
#if defined(BOARD_TWONKIEV2)
#define CONFIG_INA237
#elif defined(BOARD_TWONKIE)
#define CONFIG_INA260
#else /* BOARD_TWINKIE */
#define CONFIG_INA231
#endif
#undef CONFIG_WATCHDOG_HELP
#undef CONFIG_LID_SWITCH
#undef CONFIG_TASK_PROFILING

/* I2C ports configuration */
#define I2C_PORT_MASTER 0

/* USB configuration */
#define CONFIG_USB_PID 0x500A
/* By default, enable all console messages excepted USB */
#define CC_DEFAULT     (CC_ALL & ~CC_MASK(CC_USB))

/*
 * Allow dangerous commands all the time, since we don't have a write protect
 * switch.
 */
#define CONFIG_SYSTEM_UNLOCKED

#ifndef __ASSEMBLER__

struct rx_header;

void sniffer_init(void);

int wait_packet(int pol, uint32_t min_edges, uint32_t timeout_us);

int expect_packet(int pol, uint8_t cmd, uint32_t timeout_us);

uint8_t recording_enable(uint8_t mask);

void trace_packets(void);

void set_trace_mode(int mode);

void sniffer_trace_packet(struct rx_header rx, uint32_t *payload);
void sniffer_trace_reload(void);

/* Timer selection */
#define TIM_CLOCK_MSB  3
#define TIM_CLOCK_LSB 15
#define TIM_ADC       16

#include "gpio_signal.h"

/* ADC signal */
enum adc_channel {
	ADC_CH_CC1_PD = 0,
	ADC_CH_CC2_PD,
	/* Number of ADC channels */
	ADC_CH_COUNT
};

/* USB string indexes */
enum usb_strings {
	USB_STR_DESC = 0,
	USB_STR_VENDOR,
	USB_STR_PRODUCT,
	USB_STR_VERSION,
	USB_STR_SNIFFER,
	USB_STR_CONSOLE_NAME,
	USB_STR_COMMAND_NAME,
	USB_STR_SERIALNO,

	USB_STR_COUNT
};

/* Standard-current Rp */
#define PD_SRC_VNC           PD_SRC_DEF_VNC_MV
#define PD_SRC_RD_THRESHOLD  PD_SRC_DEF_RD_THRESH_MV

/* delay necessary for the voltage transition on the power supply */
#define PD_POWER_SUPPLY_TURN_ON_DELAY  50000 /* us */
#define PD_POWER_SUPPLY_TURN_OFF_DELAY 50000 /* us */

/* Define typical operating power and max power */
#define PD_OPERATING_POWER_MW 15000
#define PD_MAX_POWER_MW       60000
#define PD_MAX_CURRENT_MA     3000
#define PD_MAX_VOLTAGE_MV     20000

#endif /* !__ASSEMBLER__ */

/* USB interface indexes (use define rather than enum to expand them) */
#define USB_IFACE_CONSOLE 0
#define USB_IFACE_VENDOR  1

/* USB endpoint indexes (use define rather than enum to expand them) */
#define USB_EP_CONTROL   0
#define USB_EP_CONSOLE   1
#define USB_EP_COMMAND   2

#ifdef HAS_TASK_SNIFFER
#define USB_EP_SNIFFER   3
#define USB_EP_COUNT     4

#define USB_IFACE_COMMAND 2
#define USB_IFACE_COUNT   3
#else
#define USB_EP_COUNT     3
/* No IFACE_VENDOR for the sniffer */
#define USB_IFACE_COMMAND 1
#define USB_IFACE_COUNT   2
#endif

#if defined(BOARD_TWONKIEV2)
#define INA_SENSE_MOHMS 12
#elif defined(BOARD_TWONKIE)
#define INA_SENSE_MOHMS 2   /* that's mOhms not MOhms */
#else /* Twinkie */
#define INA_SENSE_MOHMS 15
#endif

#endif /* __CROS_EC_BOARD_H */

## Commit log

2020-10-14 Reference material: Data sheets, original Twinkie design
    [0000045244_Housing_Top.stp, 0000045262_Housing_bottom.stp, 180-10114-04.brd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]
2020-10-14 Initial schematics based on Twinkie
    [twonkie.kicad_pcb, twonkie.sch]
2020-11-02 Half a PCB - USB-C side laid out
    [twonkie.kicad_pcb, twonkie.sch]
2020-11-03 Ratsnest Zero \o/
    [twonkie.kicad_pcb, twonkie.sch]
2020-11-04 Silk screen, ground plane fixes, move vias out of pads, part numbers
    [twonkie.kicad_pcb, twonkie.sch]
2020-11-04 Tact switch datasheet
2020-11-05 Switch uC to combo LQFP+QFN footprint, re-route most connections
    [twonkie.kicad_pcb, twonkie.sch]
2020-11-05 Adapt silkscreen to changed layout
    [twonkie.kicad_pcb]
2020-11-06 Name and logos on silkscreen
    [twonkie.kicad_pcb]
2020-11-06 v0.9 including fabrication files
    [twonkie-B_Cu.gbl, twonkie-B_Mask.gbs, twonkie-B_Paste.gbp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]
2020-11-18 ref: Add F072CB datasheet, switch USB-C plug
2020-11-18 Many reworks based on David's and Vincent's feedback
    * The USB plug wouldn't straddle a 1.6mm board, so switched to
    a different one
    * Redid the USB section to make room for the new plug
    * Twinkie firmware needs some special pin functions I wasn't aware
    of, so some signals had to be moved to different pins
    * Misc other tweaks like merging resistor values
    [twonkie.kicad_pcb, twonkie.sch]
2020-11-18 v0.99 with fabrication files
    * Switch USB-MicroB receptacle to version with drill slots
    * Expand VBUS connections on USB-C plug
    [twonkie-B_Cu.gbl, twonkie-B_Mask.gbs, twonkie-B_Paste.gbp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]
2020-12-28 First batch of v1.0 fixes
    * Restore QFN/TQFP combo footprint for U4, make sure it stays
    * Grow some VBUS copper pours
    * Make U4 decap ground connections less solid for better soldering
    [twonkie.kicad_pcb, twonkie.sch]
2020-12-28 Save log of high speed trace impedance calculations
2020-12-28 Add photos of assembled v0.99
2020-12-28 Add relief to J2 cutout corners, update ground connections
    [twonkie.kicad_pcb]
2020-12-28 Add I2C pullup resistors
    [twonkie.kicad_pcb, twonkie.sch]
2020-12-28 Improve C2/4/5/6 solderability
    [twonkie.kicad_pcb]
2020-12-28 Solderability improvememts around J3
    * Extend J3 pads for easier hand soldering
    * Move FB1, C1 to reach pads better
    * Move J3 closer to board edge
    [twonkie.kicad_pcb]
2020-12-28 Round PCB corners
    [twonkie.kicad_pcb]
2020-12-28 Bump silkscreen version to 1.0
    [twonkie.kicad_pcb]
2020-12-29 Add back bootloader selection via USB_ID
    [twonkie.kicad_pcb, twonkie.sch]
2020-12-29 Improve U4 supply routing
    [twonkie.kicad_pcb]
2020-12-29 Switch Gerber output dir to v1.0
    [twonkie.kicad_pcb]
2021-02-13 Last minute fixes
    * Add back C8 which had accidentally been deleted
    * Flip Q4 source<->drain
    [twonkie.kicad_pcb, twonkie.sch]
2021-02-13 v1.0 fabrication files
    [twonkie-B_Cu.gbl, twonkie-B_Mask.gbs, twonkie-B_Paste.gbp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]
2021-02-16 Remove stray gerber zip
2021-02-20 Add assembly instructions with photos
2021-04-14 hw: Fix ambiguous U4 part numbers
    U4 still had plenty of references to the F042 that was originally
    designed in there, with only the value field indicating the correct
    F072. Update all fields to correctly point to the F072 part.
    Fixes #3.
    [twonkie.bom.csv, twonkie.sch]
2021-04-14 Update schematics PDF
2023-02-04 Twonkie v2.0 alpha hardware
    Upgrade the project to KiCad 6.0, fixing a whole bunch of new ERC/DRC
    errors and warnings.
    Switch from INA260 to INA237 which supports EPR voltage ranges, with
    external shunt resistors.
    Strap a previously unused pin on the STM32 to indicate the board
    revision, so firmware can detect which hardware it's running on.
    [twonkie-B_Cu.gbl, twonkie-B_Mask.gbs, twonkie-B_Paste.gbp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]
2023-02-04 v2.0: Updates based on David's review
    * Wire sense resistors according to datasheet (measured current flows
    along a long edge instead of diagonally)
    * Rotate R28 and move C9 to allow for that, this also unclutters the
    vias and traces around the INA237 north sides and improves copper
    plane shape
    * Connect inner VBUS shape to upper via group too
    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
    [twonkie-B_Cu.gbl, twonkie-B_Mask.gbs, twonkie-B_Paste.gbp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]
2023-02-04 Update USB-C receptacle part
    The EDAC part is obsolete; use a fitting drop-in replacement from GCT.
    Fixes #6.
    [twonkie.bom.csv, twonkie.kicad_pcb, twonkie.kicad_sch]
2023-02-04 Readme updates
    * Switch everything to v2.0
    * Add section about replacement parts (inspired by #6)
    * Add section for electronics noobs (inspired by #5)
2023-06-11 hw: Update AD8606 P/N, change all caps to C_Small symbol
    [twonkie.kicad_sch]
2023-06-11 fw: Add twonkiev2 board with INA237 support, fix INA260
    * Add 24-bit I2C read support to I2C code
    (and fix endian conversion bug)
    * Update ina2xx driver to use I2C builtin endian conversion
    * Move high-level functions from sniffer code into ina2xx driver
    * Support INA237 command set
    * Fix broken current reading on INA260
    * Add twonkiev2 board
    [board.c, board.h, i2c.h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]
2023-06-11 fw: Remove default board, add script to build all boards
2023-06-11 hw: Move TP1 a bit so it doesn't look like a pin 1 marker (ask me how i know)
    [twonkie.kicad_pcb]
2023-06-11 hw: Re-export BOM, schematic PDF and Gerbers
    [twonkie-B_Cu.gbl, twonkie-B_Mask.gbs, twonkie-B_Paste.gbp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]
2023-11-25 Add link to XenGi's 0.8mm PCB fork
    Closes #10
2024-04-27 Fix VCONN INA I2C address in schematic
    Just a typo - board and firmware are fine.
    Fixes #11
    [twonkie.kicad_sch]
2024-07-14 Upgrade to KiCad 8, add missing files
    [twonkie.kicad_pcb, twonkie.kicad_sch]
